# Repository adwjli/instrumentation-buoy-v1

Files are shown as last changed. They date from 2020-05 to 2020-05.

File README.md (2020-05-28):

# Instrumentation Buoy Data Logger

## Introduction

The client which I worked with in this project was working on a new concept to grow seaweed at an industrial scale (approximately 100km by 100km) in deep ocean waters tens of kilometres offshore. The seaweed plantation is kept afloat using buoys. One of the biggest challenge the client wanted to solve was how to keep the water near the surface of the ocean oxygenated to allow seaweed to grow. One idea was to use the motion of ocean waves to generate compressed air, which can be harnessed to pump air into the water to keep it oxygenated.



To aid in understanding how compressed air can be generated from ocean waves, a Instrumentation Buoy Data Logger was designed to measure various ocean metrics and record the data to a microSD card. The data logger had the following capabilities:
- Can measure water level and depth relative to the buoy.
- Can measure accelerations in all three spatial dimensions.
- Allows two pressure sensors to be connected to the board (via connectors located on the PCB)
- Designed to be completely solar powered. It is powered by an array of solar panels and a rechargeable 18650 Li-ion battery.
- A microSD card is used for data storage, but data transfer is done completely wirelessly using a XBee wireless module. The XBee module also allows over the air firmware updates. The solar-power and wireless capabilities of the data logger are necessary as the electronics will be permanently sealed away inside the buoy to ensure the electronics compartment is water-tight.

The data logger consists of two PCB assemblies sandwiched together. The smaller board is the Main Board. It contains the microcontroller, wireless module, and other digital electronics. The larger board is the Power Board which contains all the power electronics for solar charging. The entire PCB assembly is designed to be mounted in a prototype buoy, and deployed in the ocean to collect data.

The client has agreed to open source the designs.

## Gallery

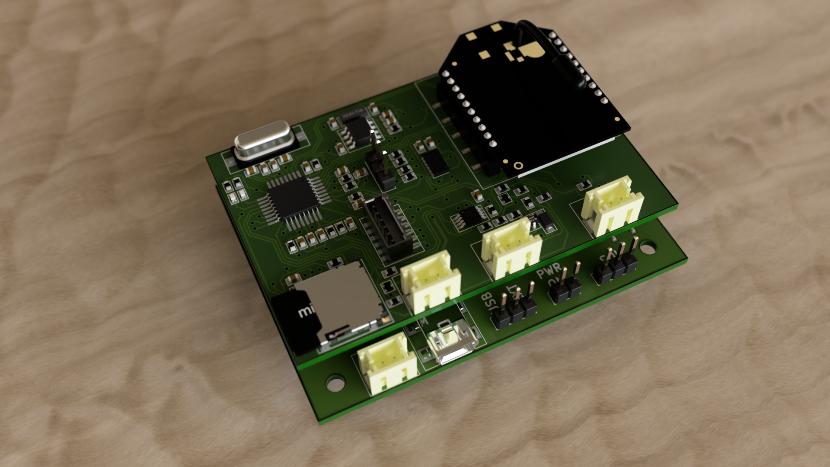
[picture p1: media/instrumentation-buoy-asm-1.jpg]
Instrumentation Buoy combined assembled - PCBA, image 1.


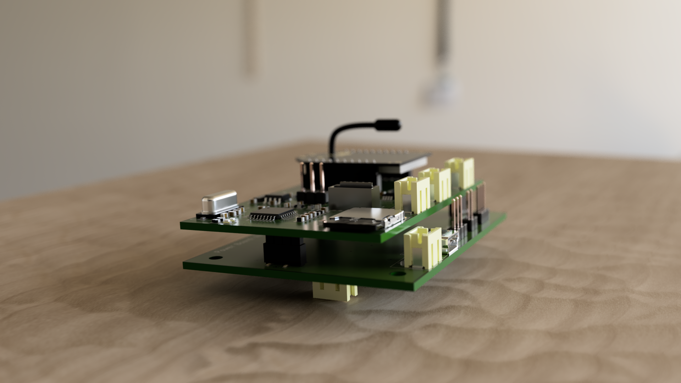
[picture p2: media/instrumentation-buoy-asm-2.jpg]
Instrumentation Buoy combined assembled - PCBA, image 2.


## PCB Assemblies
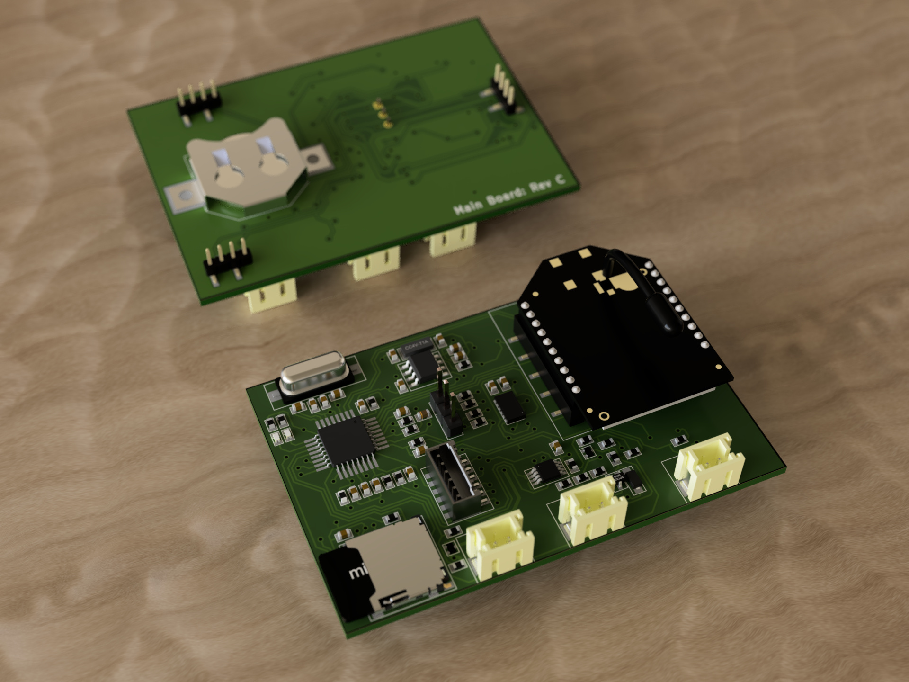
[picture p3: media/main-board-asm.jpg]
Instrumentation Buoy Main Board PCBA front and back.


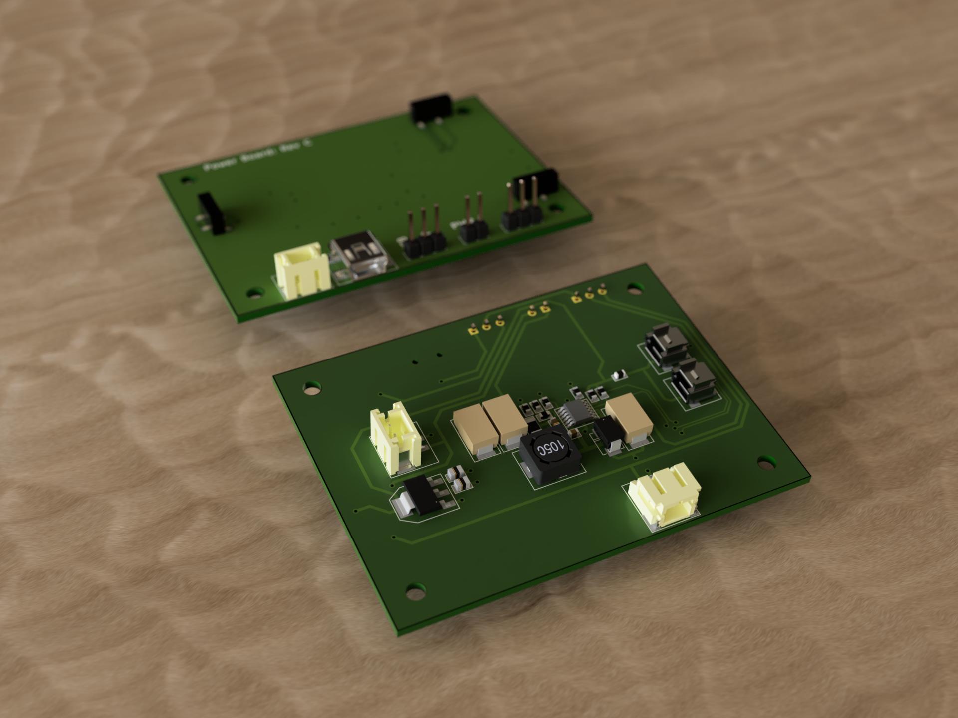
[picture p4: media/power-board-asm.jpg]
Instrumentation Buoy Power Board PCBA front and back.


## PCB Flats

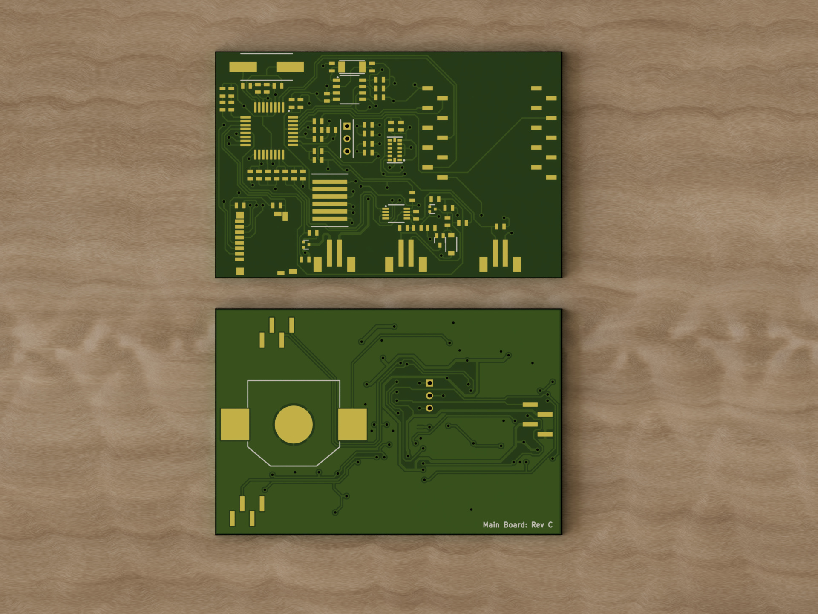
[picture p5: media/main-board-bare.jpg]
Instrumentation Buoy Main Board bare PCB.


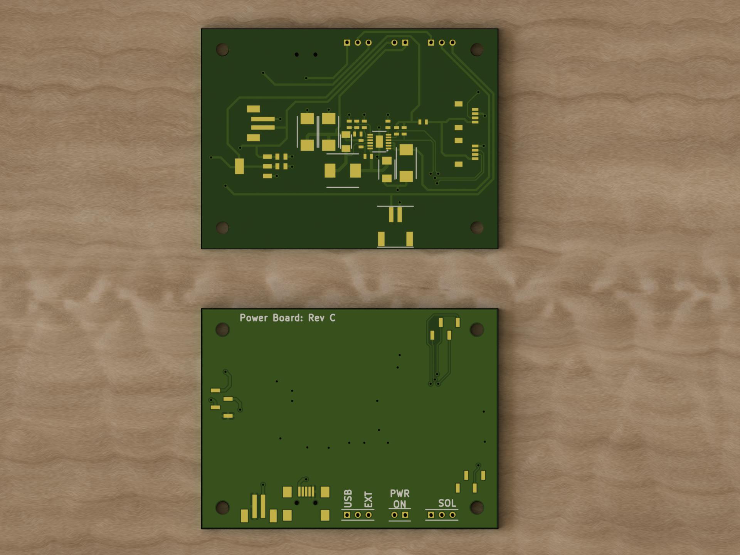
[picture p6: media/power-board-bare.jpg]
Instrumentation Buoy Power Board bare PCB.


## Copper Layers

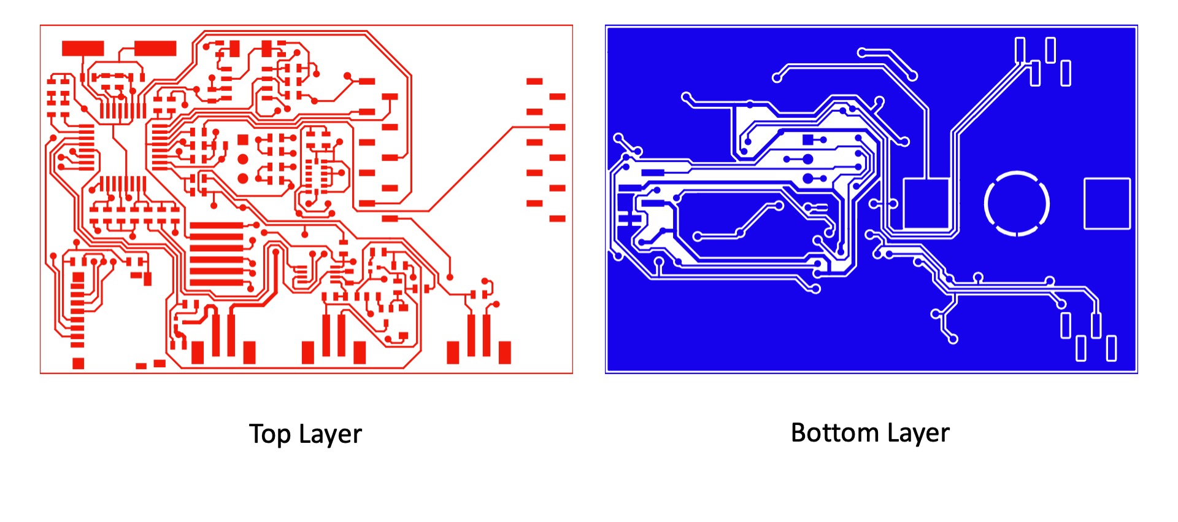
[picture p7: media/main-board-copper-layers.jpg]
Main Board - copper layers, top and bottom.


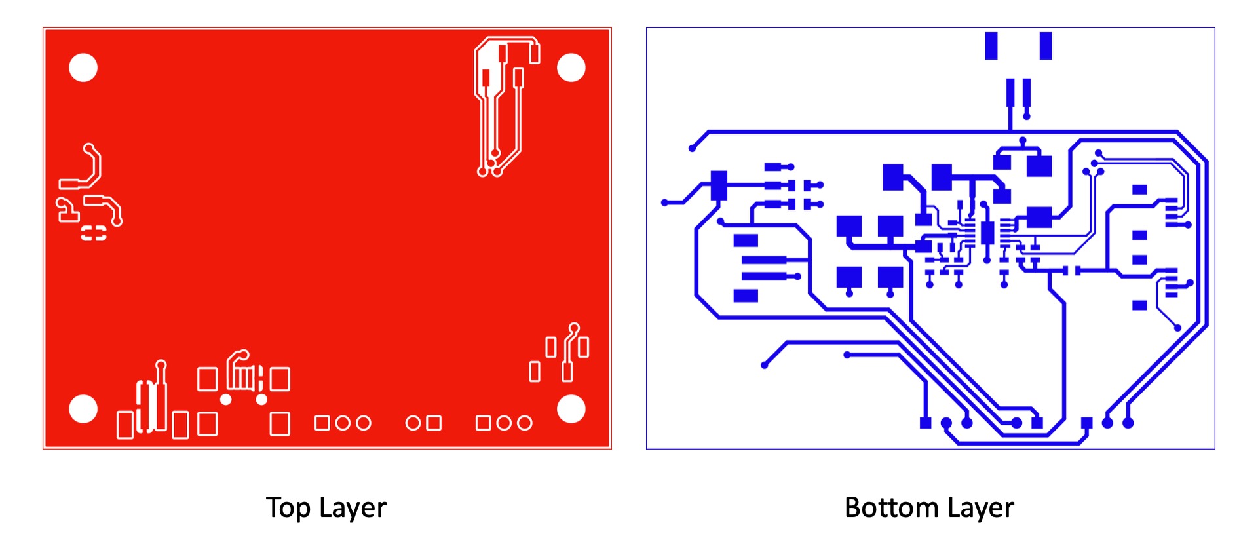
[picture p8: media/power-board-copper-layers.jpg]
Power Board - copper layers, top and bottom.


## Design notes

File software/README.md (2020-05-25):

# Firmware for Instrumentation Buoy

Compiled using the Arduino IDE. Copy the contents of the libraries folder into your Arduino `libraries` directory. To compile code, open the file `ob_datalogger.ino` and click *Verify* in the Arduino IDE.

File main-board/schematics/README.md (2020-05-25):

# Schematics

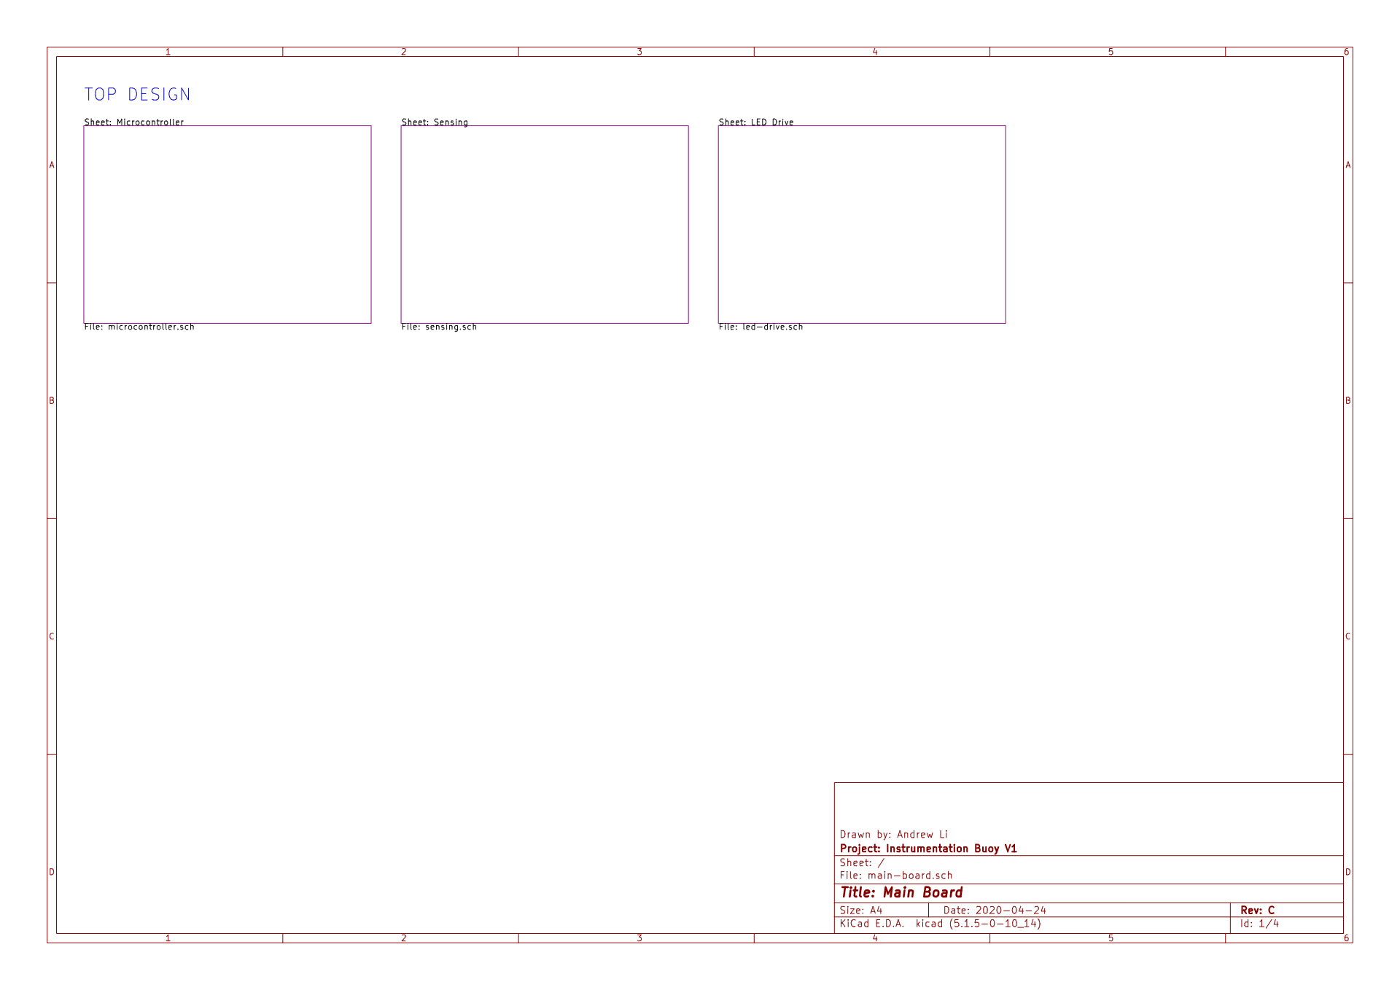
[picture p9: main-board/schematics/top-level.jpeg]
Schematics of Main Board - Top Level.


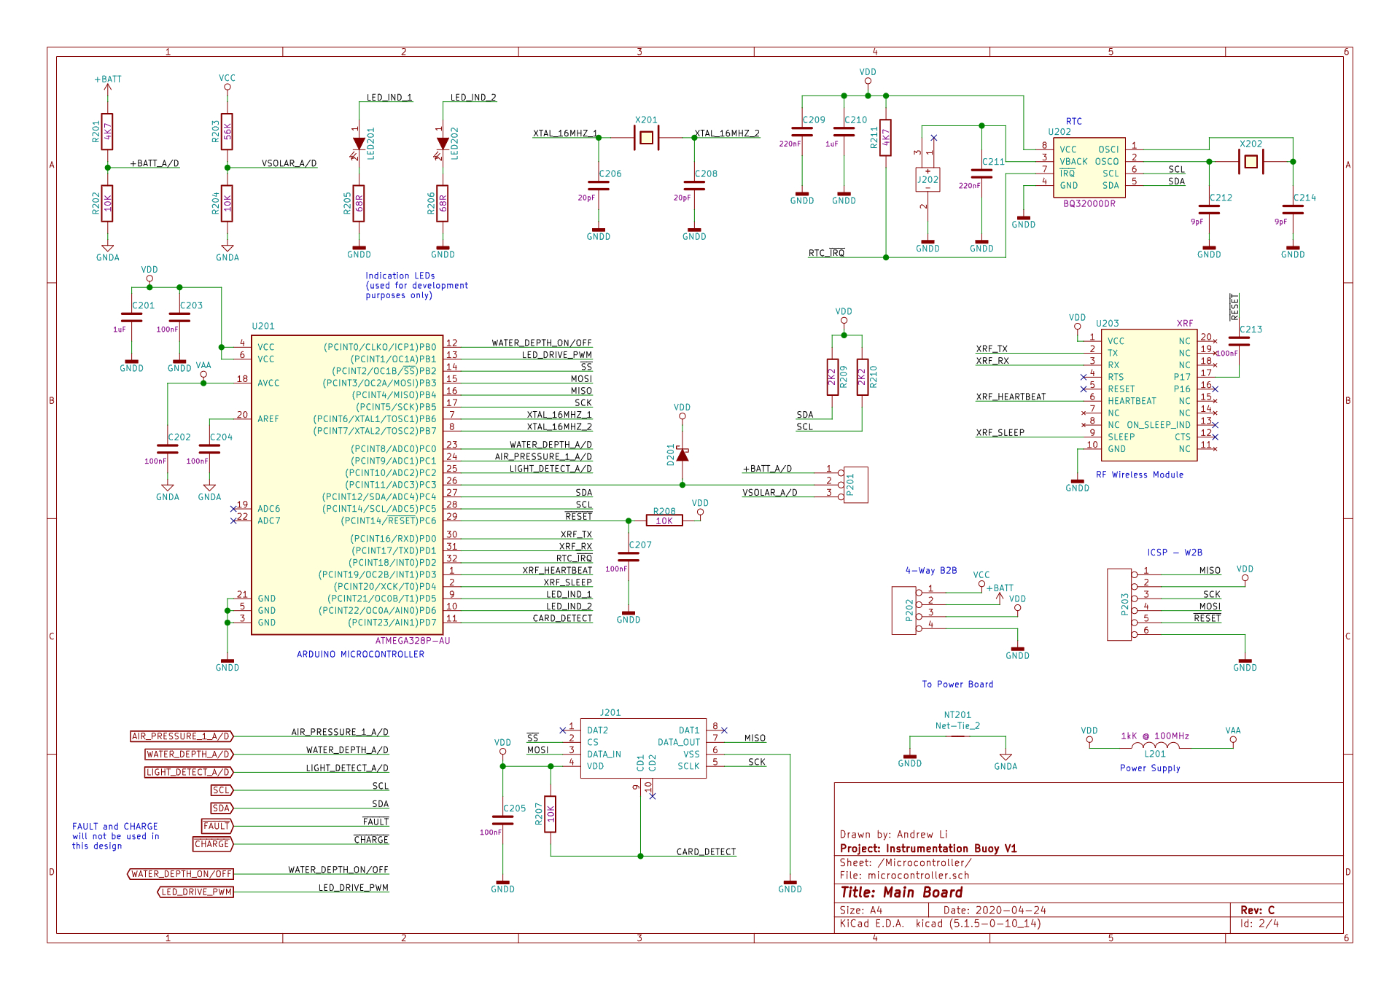
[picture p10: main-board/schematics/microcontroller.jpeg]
Schematics of Main Board - Microcontroller.


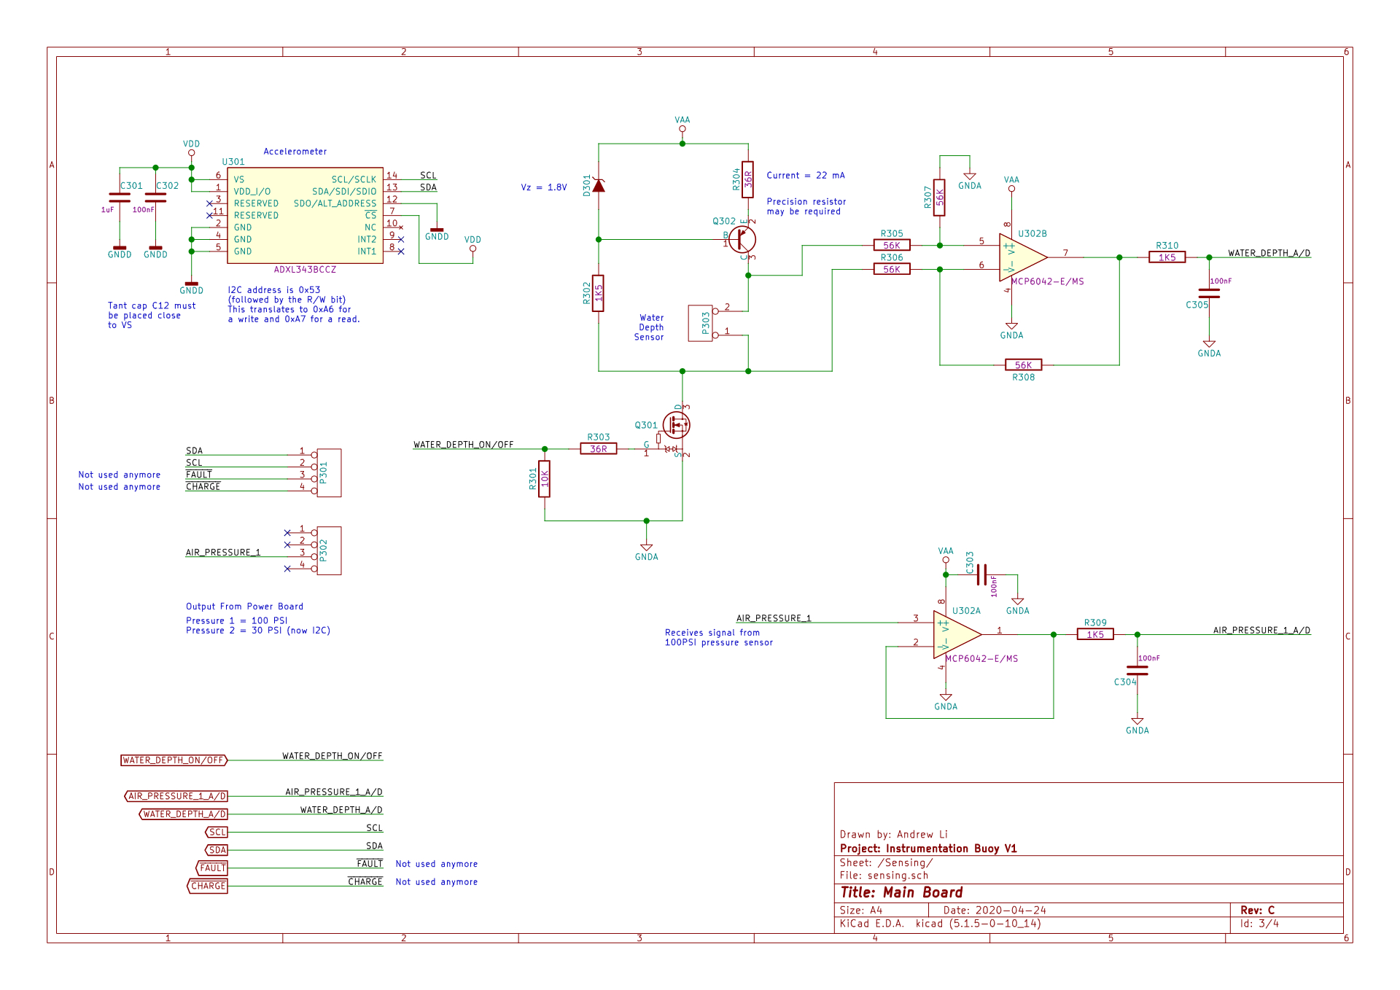
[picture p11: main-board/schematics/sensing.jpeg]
Schematics of Main Board - Sensing.


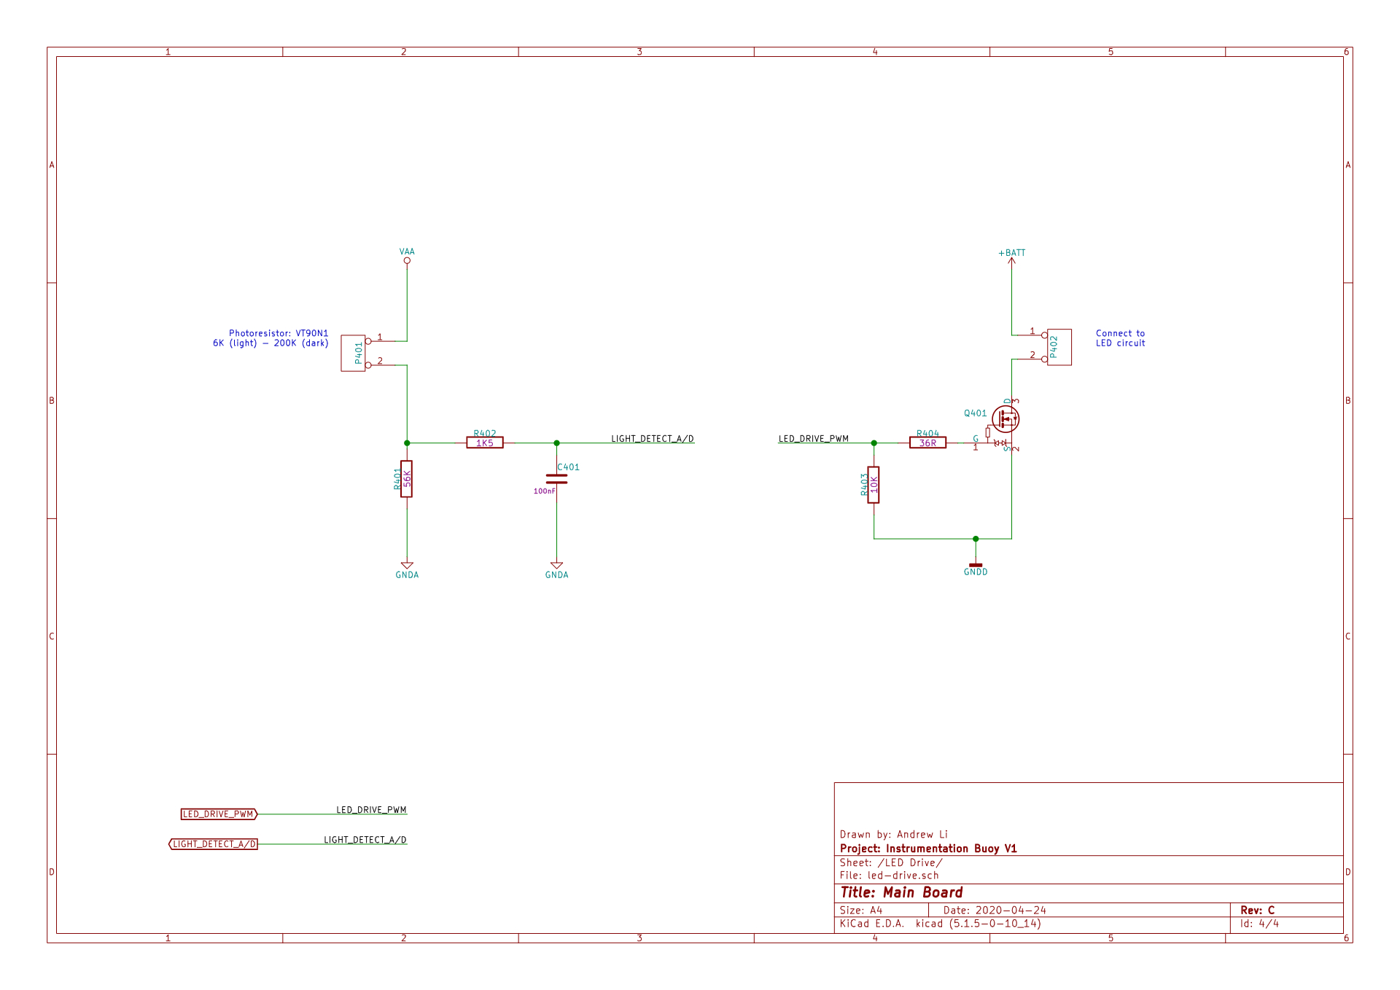
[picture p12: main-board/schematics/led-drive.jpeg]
Schematics of Main Board - LED Drive.


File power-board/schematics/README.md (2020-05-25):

# Schematics

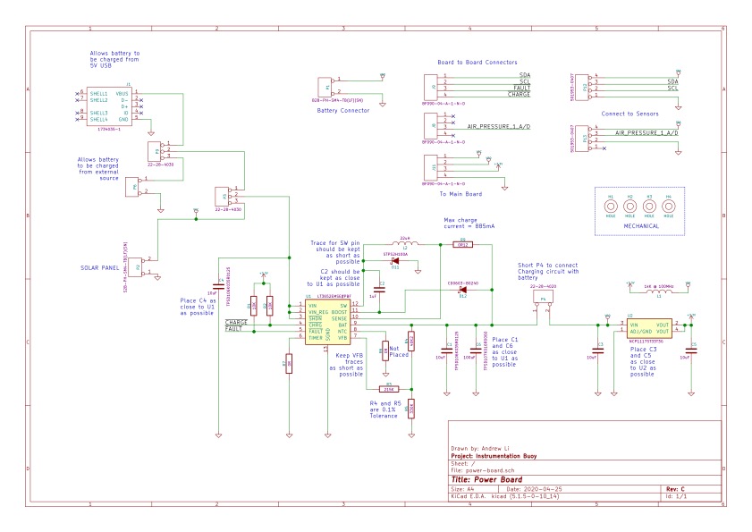
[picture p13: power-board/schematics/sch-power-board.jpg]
Schematics of Power Board.


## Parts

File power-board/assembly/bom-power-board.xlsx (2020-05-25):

Reference | Quantity | Internal Part Number | Component Value | Manufacturer | MPN | Part Description
C1 C4 | 2 | ECS00053 | 10uF | AVX | TPSD106K035R0125 | 10uF, 2917, 10%, 35V, Tantalum
C2 | 1 | ECS00052 | 1uF | Murata | GRM188R61H105KAALD | 1uF, 0603, 10%, 50V, X5R, Ceramic
C3 C5 | 2 | ECS00050 | 10uF | Murata | GRM21BR61A106KE19L | 10uF, 0805, 10%, 10V, X5R, Ceramic
C6 | 1 | ECS00054 | 100uF | AVX | TPSD107K016R0060 | 100uF, 2917, 10%, 16V, Tantalum
D11 | 1 | ECS00095 | ~ | ST Microelectronics | STPS2H100A | Schottky, Single, 2A, SMD
D12 | 1 | ECS00037 | ~ | Bourns | CD0603-B0240 | Schottky, Single, 0.1A, SMD
J1 | 1 | ECS00066 | ~ | TE Connectivity | 1734035-1 | Mini USB Type B, receptacle
J8 J9 J11 | 3 | ECS00059 | 4x1 | Global Connector Technology | BF090-04-A-1-N-D | 4-way, receptacle b-b, 2mm pitch, vertical, SMD, BF040 Series
L1 | 1 | ECS00074 | 1kK @ 100MHz | Murata | BLM18TG102TN1D | 1K @ 100MHz, 0603, 0.1A, 0R6
L2 | 1 | ECS00071 | 22uH | Murata | 46223C | 22uH, 1.8A, 0R12
P1 P6 | 2 | ECS00067 | 2x1 | JST | B2B-PH-SM4-TB(LF)(SN) | 2-way, header, 2mm pitch, vertical, SMD, PH Series
P12 P13 | 2 | ECS00068 | 4x1 | Molex | 501953-0407 | 4-way, header, 1mm pitch, right angle, SMD, Pico-Clasp 501953 Series
P2 | 1 | ECS00007 | 2x1 | JST | S2B-PH-SM4-TB(LF)(SN) | 2-way, header, 2mm pitch, right angle, SMD, PH Series
P4 | 1 | ECS00004 | 2x1 | Molex | 22-28-4020 | 2-way, header, 2.54mm pitch, vertical, through hole, KK Series
P9 P3 | 2 | ECS00013 | 3x1 | Molex | 22-28-4030 | 3-way, header, 2.54mm pitch, vertical, through hole, KK Series
R2 R1 | 2 | ECS00045 | 10K | Panasonic | ERJ3GEYJ103V | 10K, 0603, 5%, 0.1W, Thick Film
R3 | 1 | ECS00046 | 215K | Panasonic | ERJ3EKF2153V | 215K, 0603, 1%, 0.1W, Thick Film
R4 | 1 | ECS00048 | 40K2 | Panasonic | ERA3ARB4022V | 40K2, 0603, 0.1%, 0.1W, Thin Film
R5 | 1 | ECS00047 | 330K | Panasonic | ERJ3EKF3303V | 330K, 0603, 1%, 0.1W, Thick Film
R7 R6 | 2 | ECS00058 | 0R | Panasonic | ERJ3GEY0R00V | 0R, 0603, 0.1W, Jumper
R9 | 1 | ECS00055 | 0R12 | Bourns | CRL1206-FW-R120ELF | 0R12, 1206, 1%, 0.25W, Thick Film
U1 | 1 | ECS00043 | ~ | Linear Technology | LT3652EMSE#PBF | Switch Mode Charge Controller with MPPT
U2 | 1 | ECS00036 | ~ | On Semiconductor | NCP1117ST33T3G | 3.3V Linear Regulator

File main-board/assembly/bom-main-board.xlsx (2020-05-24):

Reference | Quantity | Internal Part Number | Component Value | Manufacturer | Manufacturer Part Number | Part Description
C201 C210 C301 | 3 | ECS00052 | 1uF | Murata | GRM188R61H105KAALD | 1uF, 0603, 10%, 50V, X5R, Ceramic
C203 C202 C204 C207 C205 C213 C302 C305 C304 C303 C401 | 11 | ECS00075 | 100nF | Murata | GRM188R71C104KA01D | 100nF, 0603, 10%, 16V, X7R, Ceramic
C206 C208 | 2 | ECS00077 | 20pF | Kemet | C0603C200J5GACTU | 20pF, 0603, 5%, 50V, NP0, Ceramic
C209 C211 | 2 | ECS00078 | 220nF | Murata | GRM188R71A224KA01D | 220nF, 0603, 10%, 10V, X7R, Ceramic
C212 C214 | 2 | ECS00076 | 9pF | Multicomp | MC0603N9R0D500CT | 9pF, 0603, ¬±5pF, 50V, NP0, Ceramic
D201 | 1 | ECS00037 | ~ | Bourns | CD0603-B0240 | Schottky, Single, 0.1A, SMD
D301 | 1 | ECS00072 | 1.8V | On Semiconductor | MMSZ4678T1G | Zener, 1.8V, 0.25W, SMD
J201 | 1 | ECS00065 | ~ | Amphenol Commercial Products | 114-00841-68 | Micro SD Card Holder, SMD
J202 | 1 | ECS00094 | 16mm | Memory Protection Devices | BK-868 | Retainer, 16mm Diameter Cell, SMD
L201 | 1 | ECS00074 | 1kK @ 100MHz | Murata | BLM18TG102TN1D | 1K @ 100MHz, 0603, 0.1A, 0R6
LED201 LED202 | 2 | ECS00035 | Red | Rohm | SML-310VTT86L | Red, 4mcd, 0603
P201 | 1 | ECS00013 | 3x1 | Molex | 22-28-4030 | 3-way, header, 2.54mm pitch, vertical, through hole, KK Series
P202 P302 P301 | 3 | ECS00029 | 4x1 | Global Connector Technology | BF040-04A-B2-0400-0260-0483-LD | 4-way, header, 2mm pitch, 4mm height, vertical, SMD, BF040 Series
P203 | 1 | ECS00015 | 6x1 | Molex | 87437-0673 | 6-way, header, 1.5mm pitch, vertical, SMD, Pico-SPOX Series
P303 P401 P402 | 3 | ECS00067 | 2x1 | JST | B2B-PH-SM4-TB(LF)(SN) | 2-way, header, 2mm pitch, vertical, SMD, PH Series
Q301 Q401 | 2 | ECS00087 | ~ | On Semiconductor | NTA4153NT1G | MOSFET, N-Channel, 0.915A, 0R127
Q302 | 1 | ECS00073 | ~ | NXP | BC857BW,115 | BJT, PNP, 45V, 0.1A
R201 R211 | 2 | ECS00086 | 4K7 | Bourns | CR0603-FX-4701ELF | 4K7, 0603, 1%, 0.063W, Thick Film
R202 R207 R208 R204 R301 R403 | 6 | ECS00045 | 10K | Panasonic | ERJ3GEYJ103V | 10K, 0603, 5%, 0.1W, Thick Film
R203 R307 R308 R306 R305 R401 | 6 | ECS00085 | 56K | Vishay | CRCW060356K0FKEAHP | 56K, 0603, 1%, 0.25W, Thick Film, High Power
R205 R206 | 2 | ECS00081 | 68R | Bourns | CR0603-FX-68R0ELF | 68R, 0603, 1%, 0.1W, Thick Film
R210 R209 | 2 | ECS00084 | 2K2 | Multicomp | MC0063W060312K2 | 2K2, 0603, 1%, 0.063W, Thick Film
R302 R309 R310 R402 | 4 | ECS00083 | 1K5 | Bourns | CR0603-FX-1501ELF | 1K5, 0603, 1%, 0.1W, Thick Film
R303 R304 R404 | 3 | ECS00080 | 36R | Vishay | CRCW060336R0FKEA | 36R, 0603, 0.1W, Thick Film
U201 | 1 | ECS00017 | ~ | Atmel | ATMEGA328P-AU | ATMega328P, TQFP
U202 | 1 | ECS00032 | ~ | Texas Instruments | BQ32000DR | RTC, 8SOIC
U203 | 1 | ECA00002 | ~ | Ciseco PLC | XRF | XRF Wireless UART Serial Data Module
U301 | 1 | ECS00016 | ~ | Analog Device | ADXL343BCCZ | Accelerometer, 3 axis
U302 | 1 | ECS00030 | ~ | Microchip | MCP6042-E/MS | Dual Package, 8-MSOP, Unity Gain Stable
X201 | 1 | ECS00006 | 16MHz | Fox | FOXSDLF/160-20 | Crystal, 16MHz, 30ppm, 20pF, SMD
X202 | 1 | ECS00005 | 32.768kHz | Micro Crystal Switzerland | CC4V-T1A 32.768KHZ +-20PPM 9PF | Crystal, 32.768kHz, 20ppm, 9pF, SMD

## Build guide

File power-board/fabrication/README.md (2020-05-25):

# Fabrication Drawing

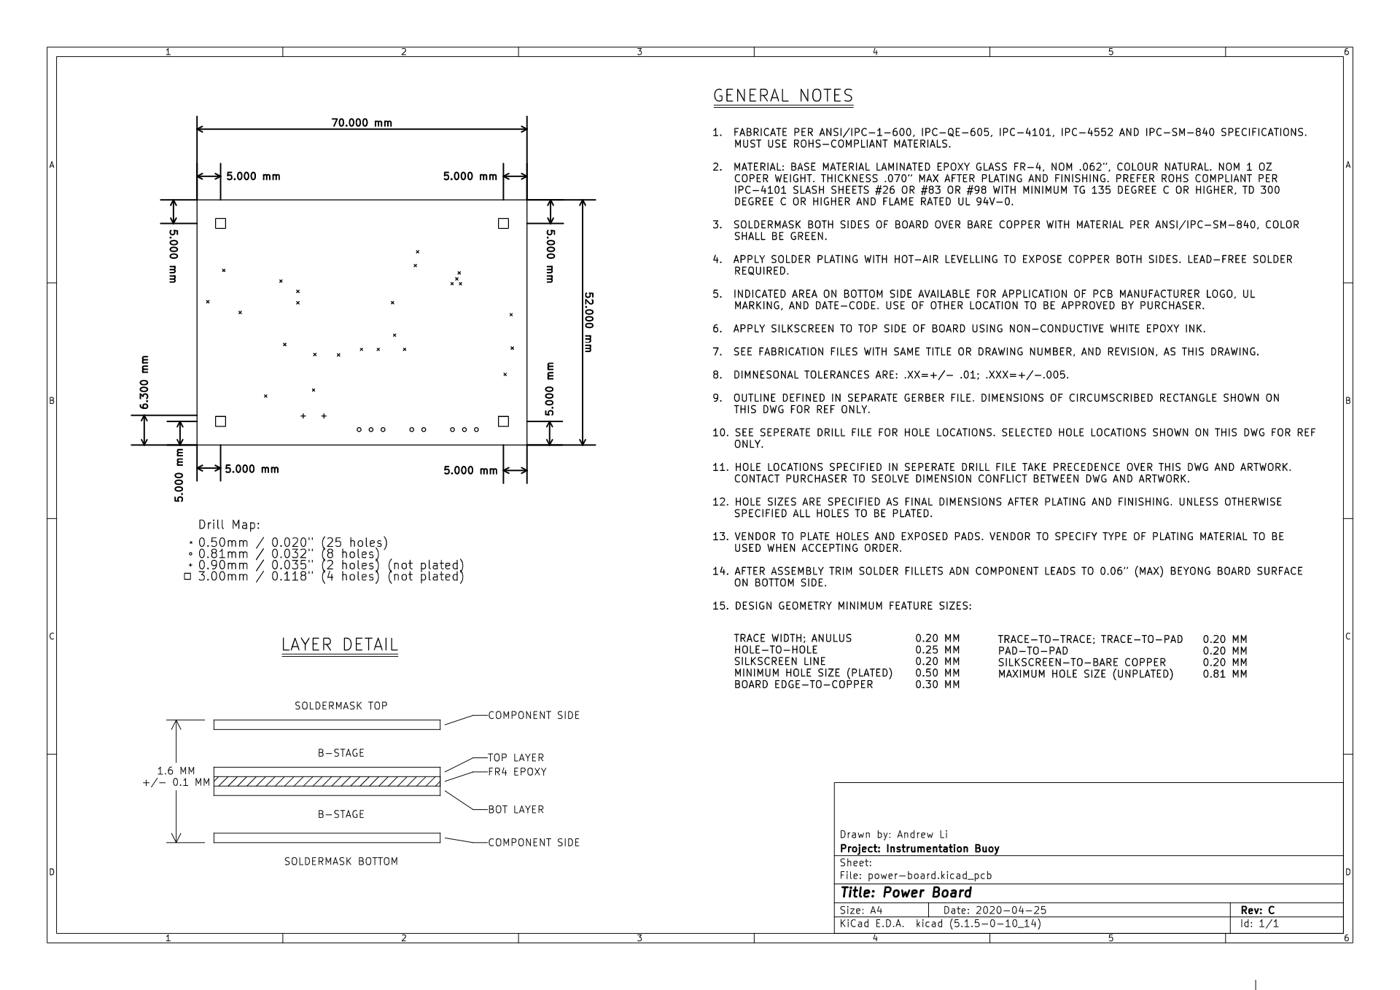
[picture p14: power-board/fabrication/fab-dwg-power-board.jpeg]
Fabrication drawing


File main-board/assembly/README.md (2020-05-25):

# Assembly Drawing

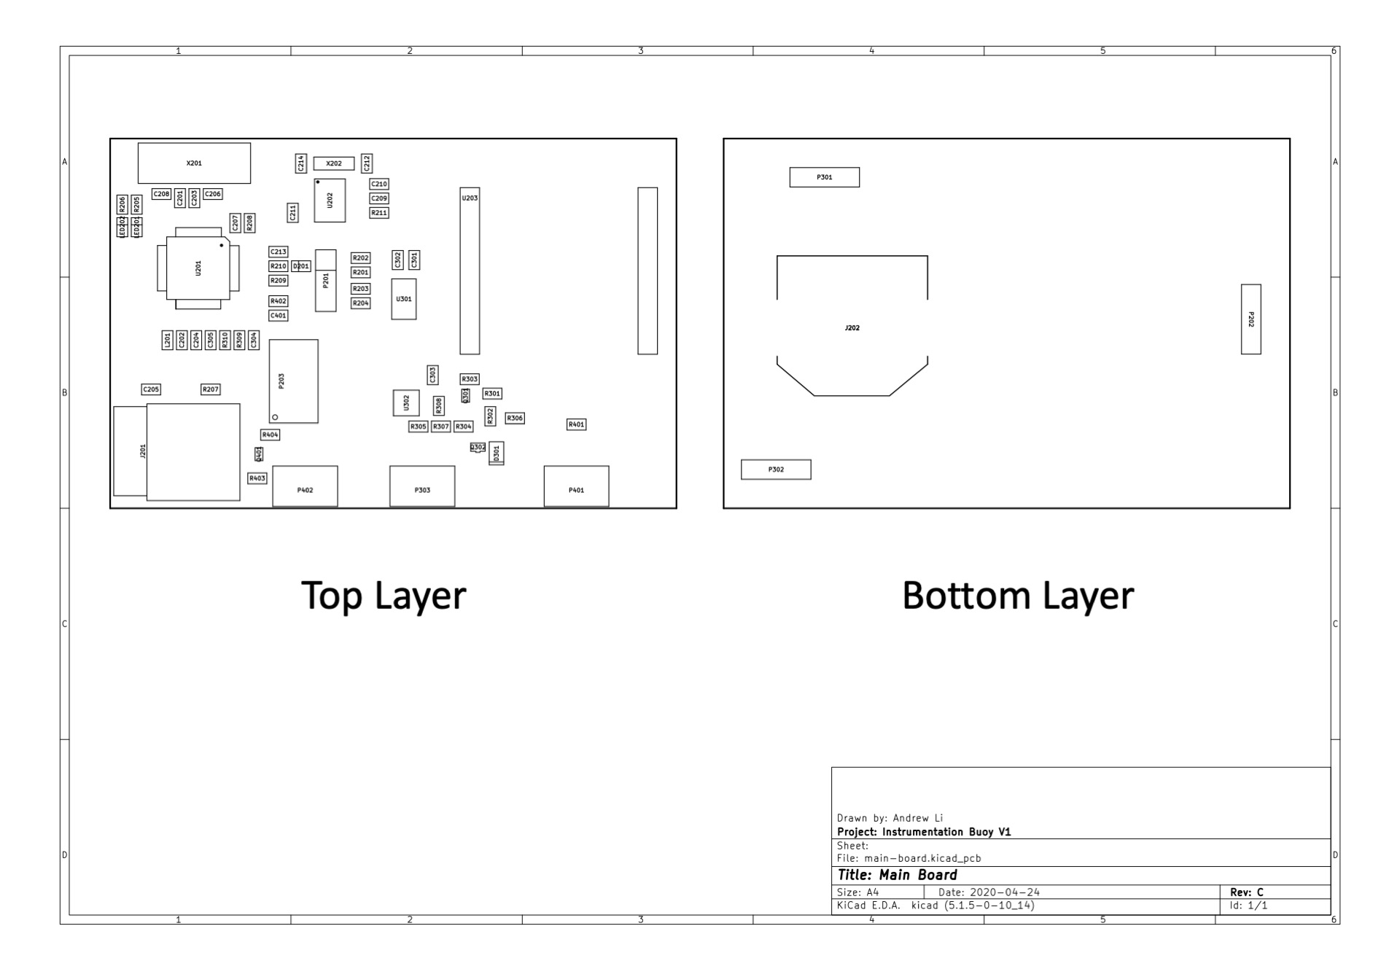
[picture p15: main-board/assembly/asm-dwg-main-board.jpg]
Assembly Drawing.


## Bill of Materials

| Reference 	|  Quantity 	| Internal Part Number 	|  Component Value 	|  Manufacturer 	|  MPN 	|  Part Description 	|
|---	|---	|---	|---	|---	|---	|---	|
| C201 C210 C301 	| 3 	| ECS00052 	| 1uF 	| Murata 	| GRM188R61H105KAALD 	| 1uF, 0603, 10%, 50V, X5R, Ceramic 	|
| C203 C202 C204 C207 C205 C213 C302 C305 C304 C303 C401  	| 11 	| ECS00075 	| 100nF 	| Murata 	| GRM188R71C104KA01D 	| 100nF, 0603, 10%, 16V, X7R, Ceramic 	|
| C206 C208 	| 2 	| ECS00077 	| 20pF 	| Kemet 	| C0603C200J5GACTU 	| 20pF, 0603, 5%, 50V, NP0, Ceramic 	|
| C209 C211 	| 2 	| ECS00078 	| 220nF 	| Murata 	| GRM188R71A224KA01D 	| 220nF, 0603, 10%, 10V, X7R, Ceramic 	|
| C212 C214 	| 2 	| ECS00076 	| 9pF 	| Multicomp 	| MC0603N9R0D500CT 	| 9pF, 0603, ¬±5pF, 50V, NP0, Ceramic 	|
| D201 	| 1 	| ECS00037 	| ~ 	| Bourns 	| CD0603-B0240 	| Schottky, Single, 0.1A, SMD 	|
| D301 	| 1 	| ECS00072 	| 1.8V 	| On Semiconductor 	| MMSZ4678T1G 	| Zener, 1.8V, 0.25W, SMD 	|
| J201 	| 1 	| ECS00065 	| ~ 	| Amphenol Commercial Products 	| 114-00841-68 	| Micro SD Card Holder, SMD 	|
| J202 	| 1 	| ECS00094 	| 16mm 	| Memory Protection Devices 	| BK-868 	| Retainer, 16mm Diameter Cell, SMD 	|
| L201 	| 1 	| ECS00074 	| 1kK @ 100MHz 	| Murata 	| BLM18TG102TN1D 	| 1K @ 100MHz, 0603, 0.1A, 0R6 	|
| LED201 LED202 	| 2 	| ECS00035 	| Red 	| Rohm 	| SML-310VTT86L 	| Red, 4mcd, 0603 	|
| P201 	| 1 	| ECS00013 	| 3x1 	| Molex 	| 22-28-4030 	| 3-way, header, 2.54mm pitch, vertical, through hole, KK Series 	|
| P202 P302 P301 	| 3 	| ECS00029 	| 4x1 	| Global Connector Technology  	| BF040-04A-B2-0400-0260-0483-LD 	| 4-way, header, 2mm pitch, 4mm height, vertical, SMD, BF040 Series 	|
| P203 	| 1 	| ECS00015 	| 6x1 	| Molex 	| 87437-0673 	| 6-way, header, 1.5mm pitch, vertical, SMD, Pico-SPOX Series 	|
| P303 P401 P402 	| 3 	| ECS00067 	| 2x1 	| JST 	| B2B-PH-SM4-TB(LF)(SN) 	| 2-way, header, 2mm pitch, vertical, SMD, PH Series 	|
| Q301 Q401 	| 2 	| ECS00087 	| ~ 	| On Semiconductor 	| NTA4153NT1G 	| MOSFET, N-Channel, 0.915A, 0R127 	|
| Q302 	| 1 	| ECS00073 	| ~ 	| NXP 	| BC857BW,115 	| BJT, PNP, 45V, 0.1A 	|
| R201 R211 	| 2 	| ECS00086 	| 4K7 	| Bourns 	| CR0603-FX-4701ELF 	| 4K7, 0603, 1%, 0.063W, Thick Film 	|
| R202 R207 R208 R204 R301 R403 	| 6 	| ECS00045 	| 10K 	| Panasonic 	| ERJ3GEYJ103V 	| 10K, 0603, 5%, 0.1W, Thick Film 	|
| R203 R307 R308 R306 R305 R401 	| 6 	| ECS00085 	| 56K 	| Vishay 	| CRCW060356K0FKEAHP 	| 56K, 0603, 1%, 0.25W, Thick Film, High Power 	|
| R205 R206 	| 2 	| ECS00081 	| 68R 	| Bourns 	| CR0603-FX-68R0ELF 	| 68R, 0603, 1%, 0.1W,  Thick Film 	|
| R210 R209 	| 2 	| ECS00084 	| 2K2 	| Multicomp 	| MC0063W060312K2 	| 2K2, 0603, 1%, 0.063W, Thick Film 	|
| R302 R309 R310 R402 	| 4 	| ECS00083 	| 1K5 	| Bourns 	| CR0603-FX-1501ELF 	| 1K5, 0603, 1%,  0.1W, Thick Film 	|
| R303 R304 R404 	| 3 	| ECS00080 	| 36R 	| Vishay 	| CRCW060336R0FKEA 	| 36R, 0603, 0.1W,  Thick Film 	|
| U201 	| 1 	| ECS00017 	| ~ 	| Atmel 	| ATMEGA328P-AU 	| ATMega328P, TQFP 	|
| U202 	| 1 	| ECS00032 	| ~ 	| Texas Instruments 	| BQ32000DR 	| RTC, 8SOIC 	|
| U203 	| 1 	| ECA00002 	| ~ 	| Ciseco PLC 	| XRF 	| XRF Wireless UART Serial Data Module 	|
| U301 	| 1 	| ECS00016 	| ~ 	| Analog Device 	| ADXL343BCCZ 	| Accelerometer, 3 axis 	|
| U302 	| 1 	| ECS00030 	| ~ 	| Microchip 	| MCP6042-E/MS 	| Dual Package, 8-MSOP, Unity Gain Stable 	|
| X201 	| 1 	| ECS00006 	| 16MHz 	| Fox 	| FOXSDLF/160-20 	| Crystal, 16MHz, 30ppm, 20pF, SMD 	|
| X202 	| 1 	| ECS00005 	| 32.768kHz 	| Micro Crystal Switzerland 	| CC4V-T1A 32.768KHZ +-20PPM 9PF 	| Crystal, 32.768kHz, 20ppm, 9pF, SMD 	|

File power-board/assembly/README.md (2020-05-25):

# Assembly Drawing

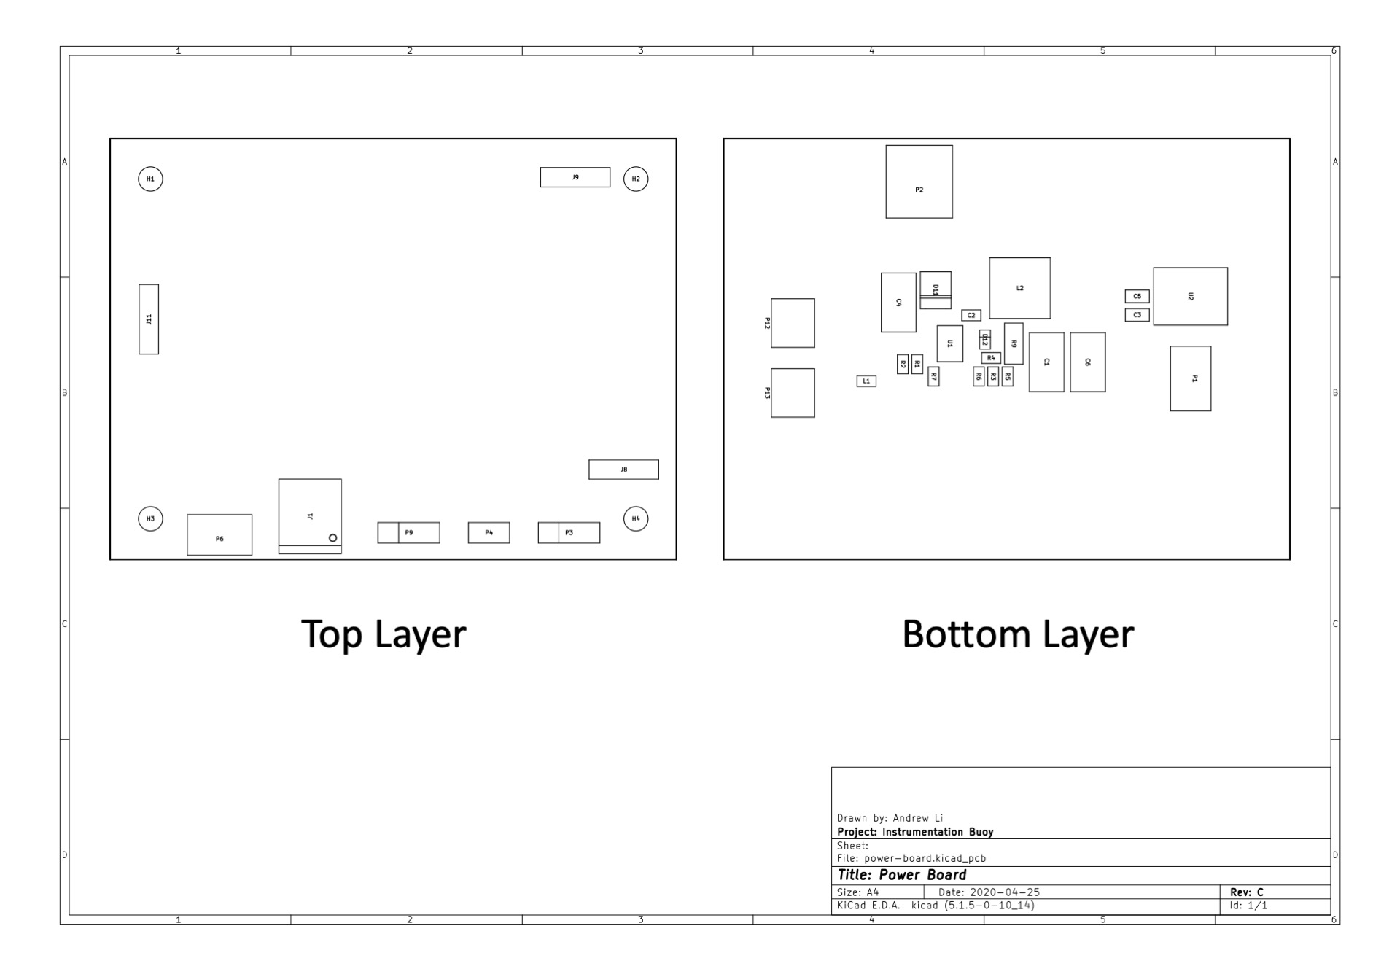
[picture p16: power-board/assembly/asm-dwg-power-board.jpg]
Assembly drawing


## Bill of Materials

| Reference  	|  Quantity 	|  Internal Part Number 	|  Component Value 	|  Manufacturer 	| MPN 	|  Part Description 	|
|---	|:---:	|---	|---	|---	|---	|---	|
| C1 C4 	| 2 	| ECS00053 	| 10uF 	| AVX 	| TPSD106K035R0125 	| 10uF, 2917, 10%, 35V, Tantalum 	|
| C2 	| 1 	| ECS00052 	| 1uF 	| Murata 	| GRM188R61H105KAALD 	| 1uF, 0603, 10%, 50V, X5R, Ceramic 	|
| C3 C5 	| 2 	| ECS00050 	| 10uF 	| Murata 	| GRM21BR61A106KE19L 	| 10uF, 0805, 10%, 10V, X5R, Ceramic 	|
| C6 	| 1 	| ECS00054 	| 100uF 	| AVX 	| TPSD107K016R0060 	| 100uF, 2917, 10%, 16V, Tantalum 	|
| D11 	| 1 	| ECS00095 	| ~ 	| ST Microelectronics 	| STPS2H100A 	| Schottky, Single, 2A, SMD 	|
| D12 	| 1 	| ECS00037 	| ~ 	| Bourns 	| CD0603-B0240 	| Schottky, Single, 0.1A, SMD 	|
| J1 	| 1 	| ECS00066 	| ~ 	| TE Connectivity 	| 1734035-1 	| Mini USB Type B, receptacle 	|
| J8 J9 J11  	| 3 	| ECS00059 	| 4x1 	| Global Connector Technology 	| BF090-04-A-1-N-D 	| 4-way, receptacle b-b, 2mm pitch, vertical, SMD, BF040 Series 	|
| L1 	| 1 	| ECS00074 	| 1kK @ 100MHz 	| Murata 	| BLM18TG102TN1D 	| 1K @ 100MHz, 0603, 0.1A, 0R6 	|
| L2 	| 1 	| ECS00071 	| 22uH 	| Murata 	| 46223C 	| 22uH, 1.8A, 0R12 	|
| P1 P6 	| 2 	| ECS00067 	| 2x1 	| JST 	| B2B-PH-SM4-TB(LF)(SN) 	| 2-way, header, 2mm pitch, vertical, SMD, PH Series 	|
| P12 P13 	| 2 	| ECS00068 	| 4x1 	| Molex 	| 501953-0407 	| 4-way, header, 1mm pitch, right angle, SMD, Pico-Clasp 501953 Series 	|
| P2 	| 1 	| ECS00007 	| 2x1 	| JST 	| S2B-PH-SM4-TB(LF)(SN) 	| 2-way, header, 2mm pitch, right angle, SMD, PH Series 	|
| P4 	| 1 	| ECS00004 	| 2x1 	| Molex 	| 22-28-4020 	| 2-way, header, 2.54mm pitch, vertical, through hole, KK Series 	|
| P9 P3 	| 2 	| ECS00013 	| 3x1 	| Molex 	| 22-28-4030 	| 3-way, header, 2.54mm pitch, vertical, through hole, KK Series 	|
| R2 R1 	| 2 	| ECS00045 	| 10K 	| Panasonic 	| ERJ3GEYJ103V 	| 10K, 0603, 5%, 0.1W, Thick Film 	|
| R3 	| 1 	| ECS00046 	| 215K 	| Panasonic 	| ERJ3EKF2153V 	| 215K, 0603, 1%, 0.1W, Thick Film 	|
| R4 	| 1 	| ECS00048 	| 40K2 	| Panasonic 	| ERA3ARB4022V 	| 40K2, 0603, 0.1%, 0.1W, Thin Film 	|
| R5 	| 1 	| ECS00047 	| 330K 	| Panasonic 	| ERJ3EKF3303V 	| 330K,  0603, 1%, 0.1W, Thick Film 	|
| R7 R6 	| 2 	| ECS00058 	| 0R 	| Panasonic 	| ERJ3GEY0R00V 	| 0R, 0603, 0.1W, Jumper 	|
| R9 	| 1 	| ECS00055 	| 0R12 	| Bourns 	| CRL1206-FW-R120ELF 	| 0R12, 1206, 1%, 0.25W, Thick Film 	|
| U1 	| 1 	| ECS00043 	| ~ 	| Linear Technology 	| LT3652EMSE#PBF 	| Switch Mode Charge Controller with MPPT 	|
| U2 	| 1 	| ECS00036 	| ~ 	| On Semiconductor 	| NCP1117ST33T3G 	| 3.3V Linear Regulator 	|

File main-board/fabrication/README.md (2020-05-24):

# Fabrication Drawing

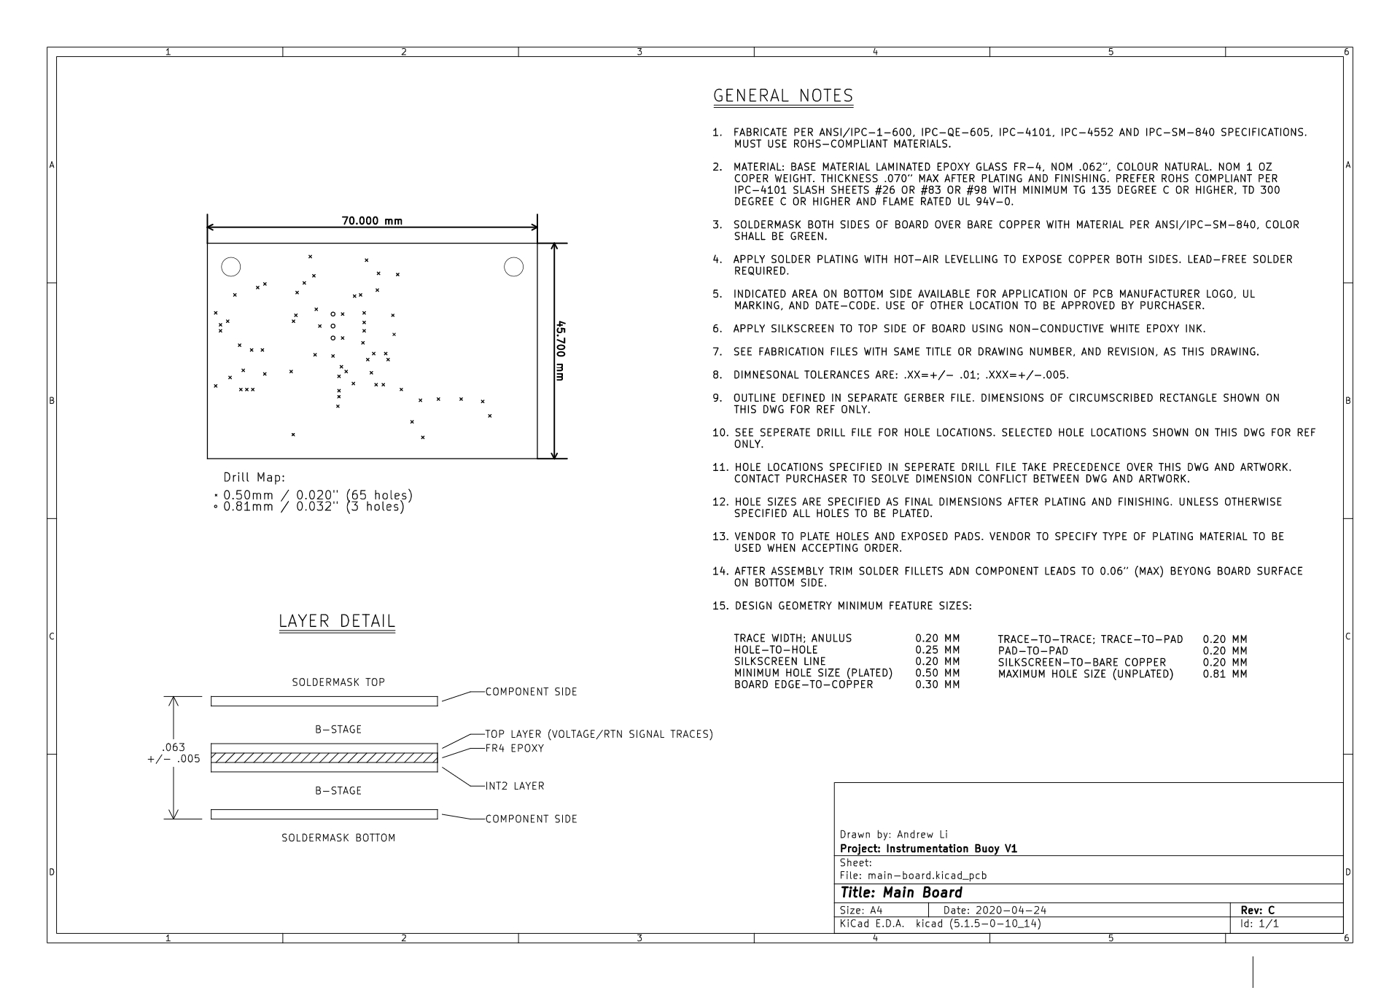
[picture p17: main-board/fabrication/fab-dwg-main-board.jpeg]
Fabrication Drawing.


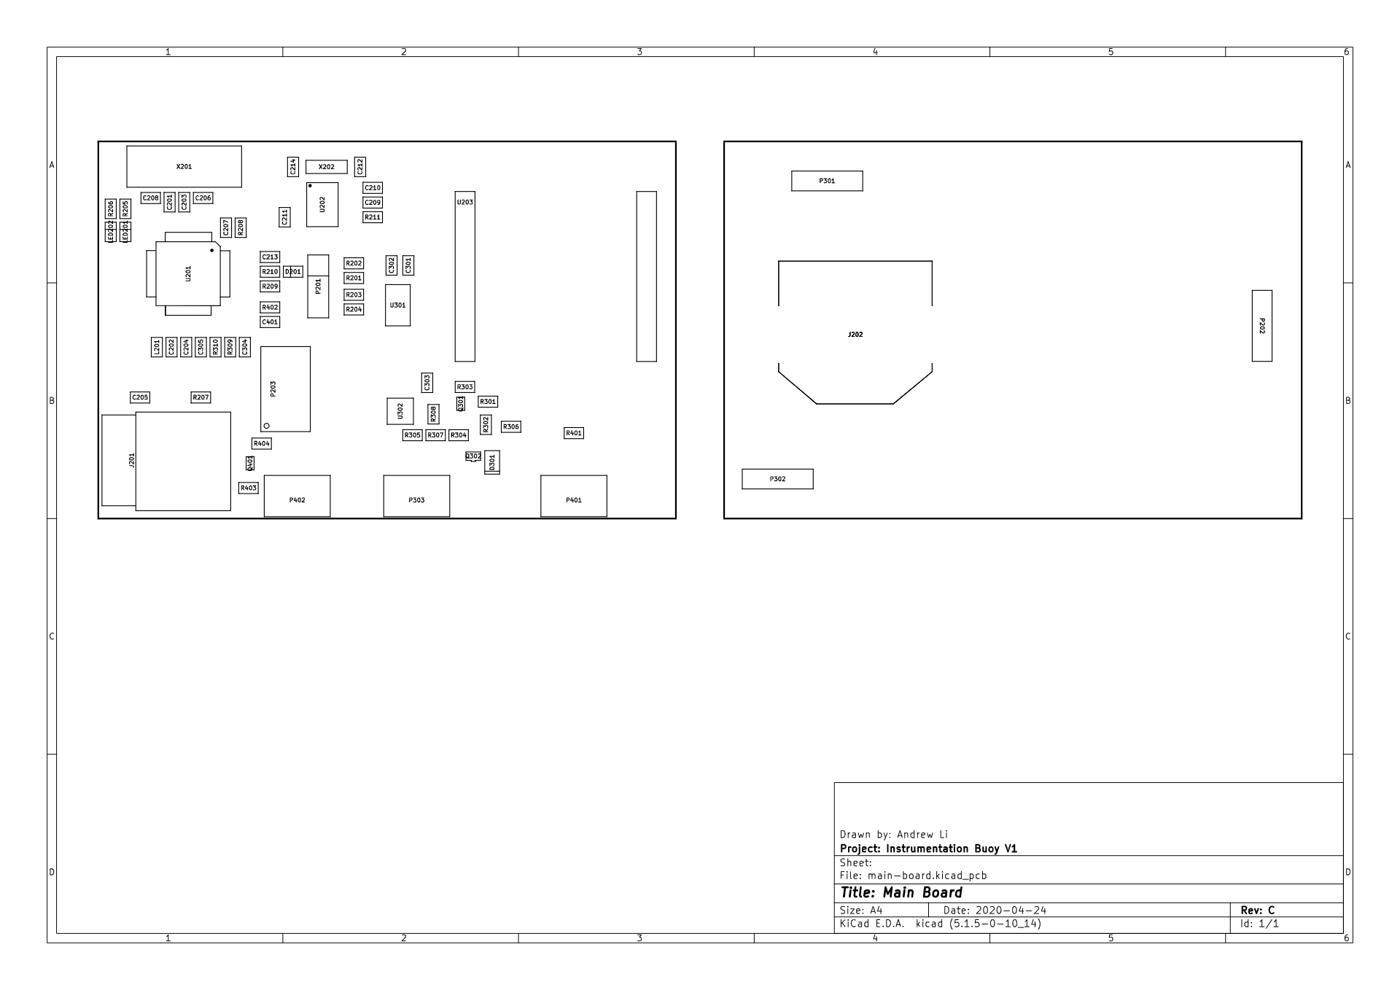
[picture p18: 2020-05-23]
main-board/assembly/asm-dwg-main-board.jpeg

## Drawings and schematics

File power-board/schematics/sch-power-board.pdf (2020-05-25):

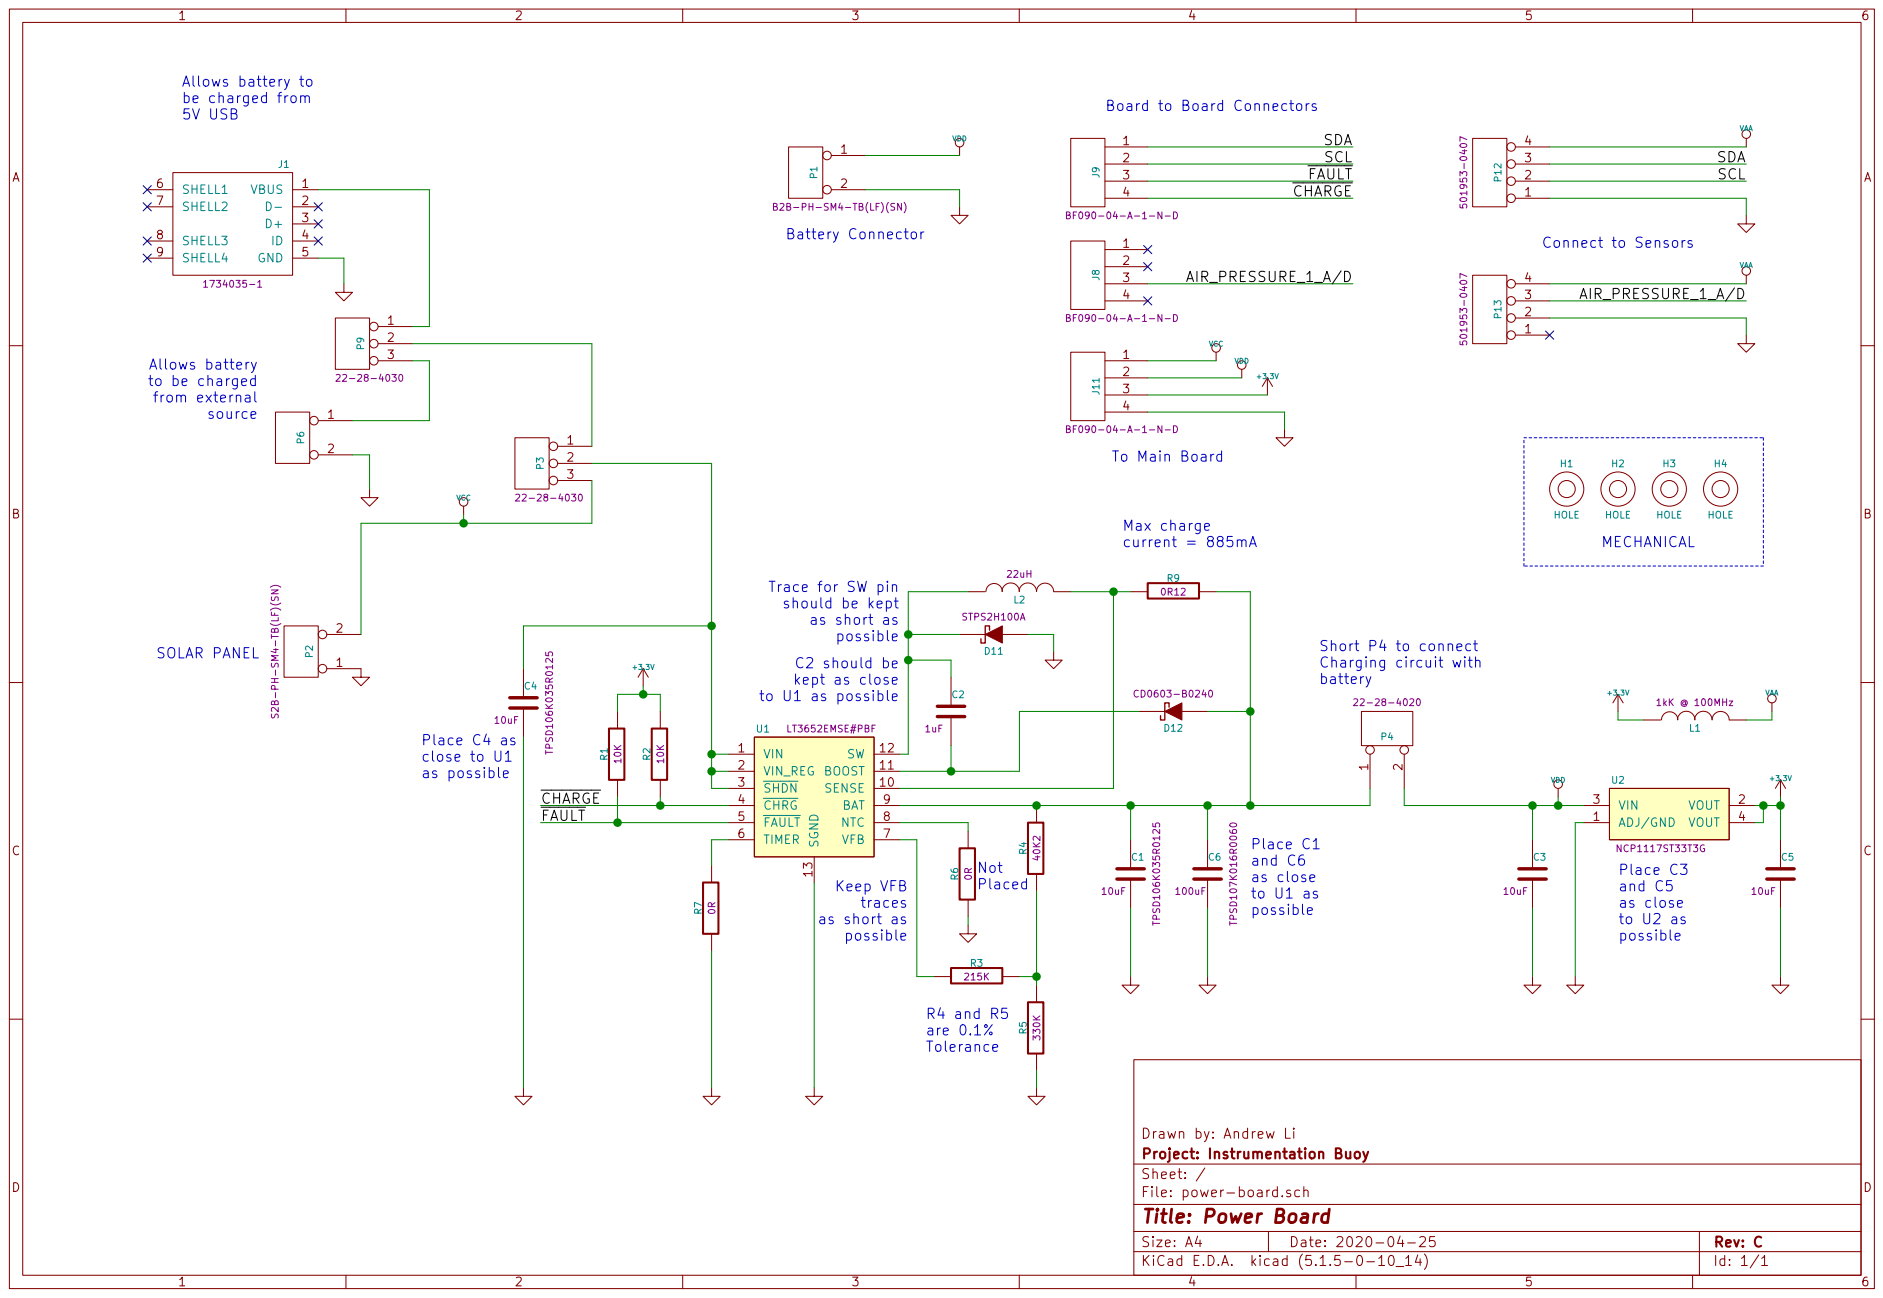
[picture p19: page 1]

Board to Board Connectors

CHARGE

VAA H4 HOLE H3 HOLE H2 HOLE H1 HOLE D11 STPS2H100A

current = 885mA Not Placed R4 and R5

Trace for SW pin
should be kept as short as possible

traces as short as possible

File: power-board.sch Sheet: / Project: Instrumentation Buoy

Id: 1/1 Title: Power Board

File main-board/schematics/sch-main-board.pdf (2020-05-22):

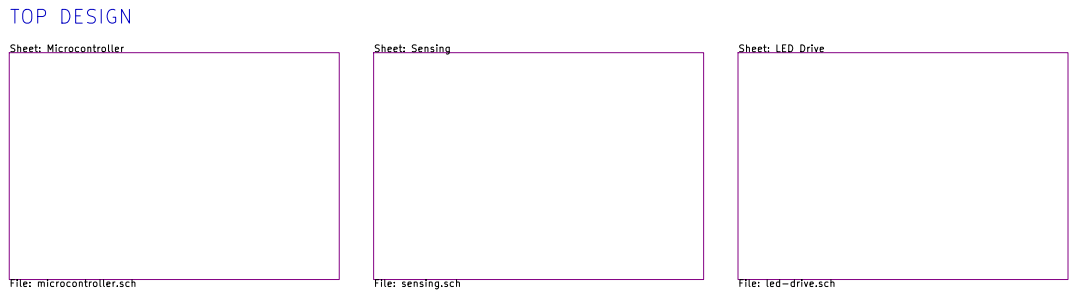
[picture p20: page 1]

Drawn by: Andrew Li
File: main-board.sch Sheet: / Project: Instrumentation Buoy V1

Id: 1/4 Title: Main Board

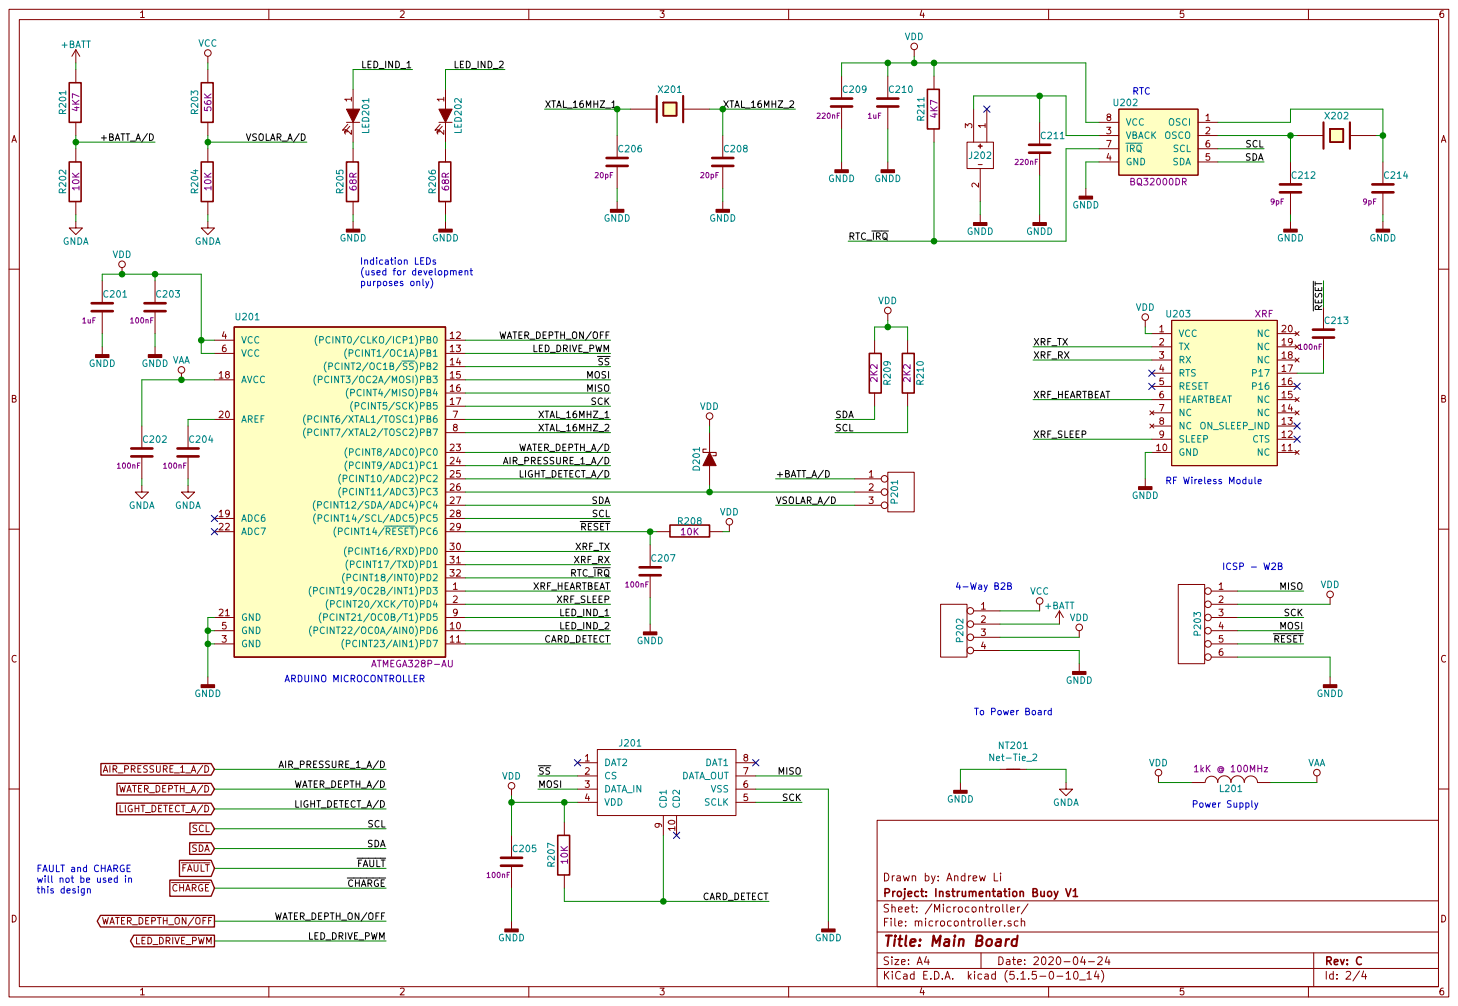
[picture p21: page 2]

VDD
ICSP - W2B RF Wireless Module RTC
RTC_IRQ

FAULT and CHARGE will not be used in

File: microcontroller.sch Sheet: /Microcontroller/ Project: Instrumentation Buoy V1

Id: 2/4 Title: Main Board

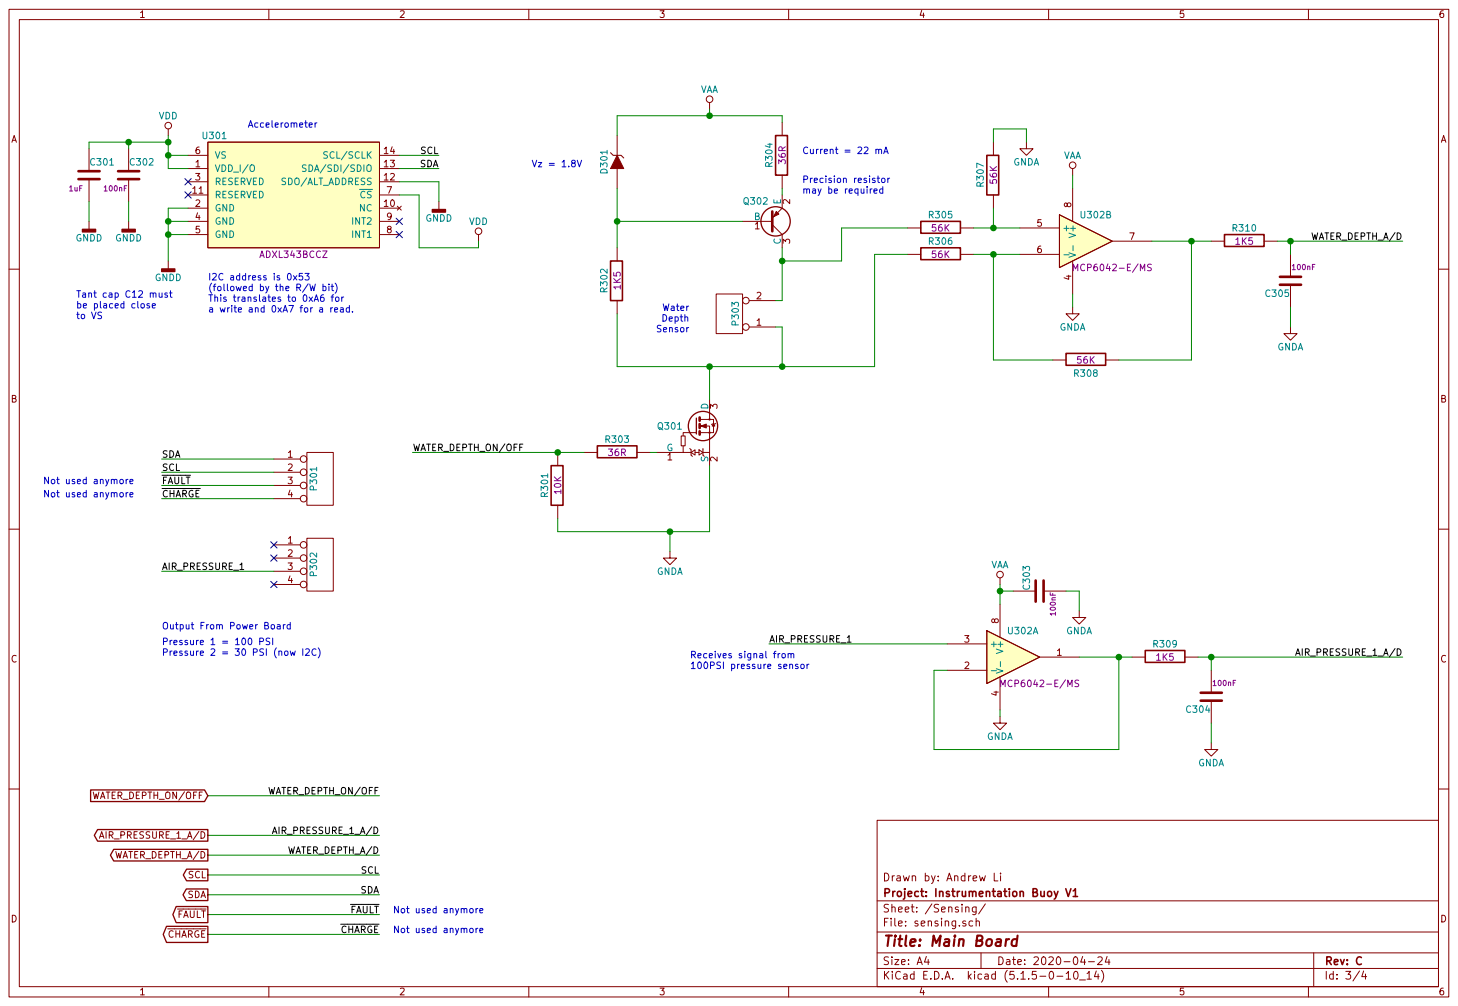
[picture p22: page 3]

Output From Power Board Pressure 1 = 100 PSI Pressure 2 = 30 PSI (now I2C)

Drawn by: Andrew Li
Project: Instrumentation Buoy V1
Sheet: /Sensing/
File: sensing.sch
Id: 3/4 Title: Main Board

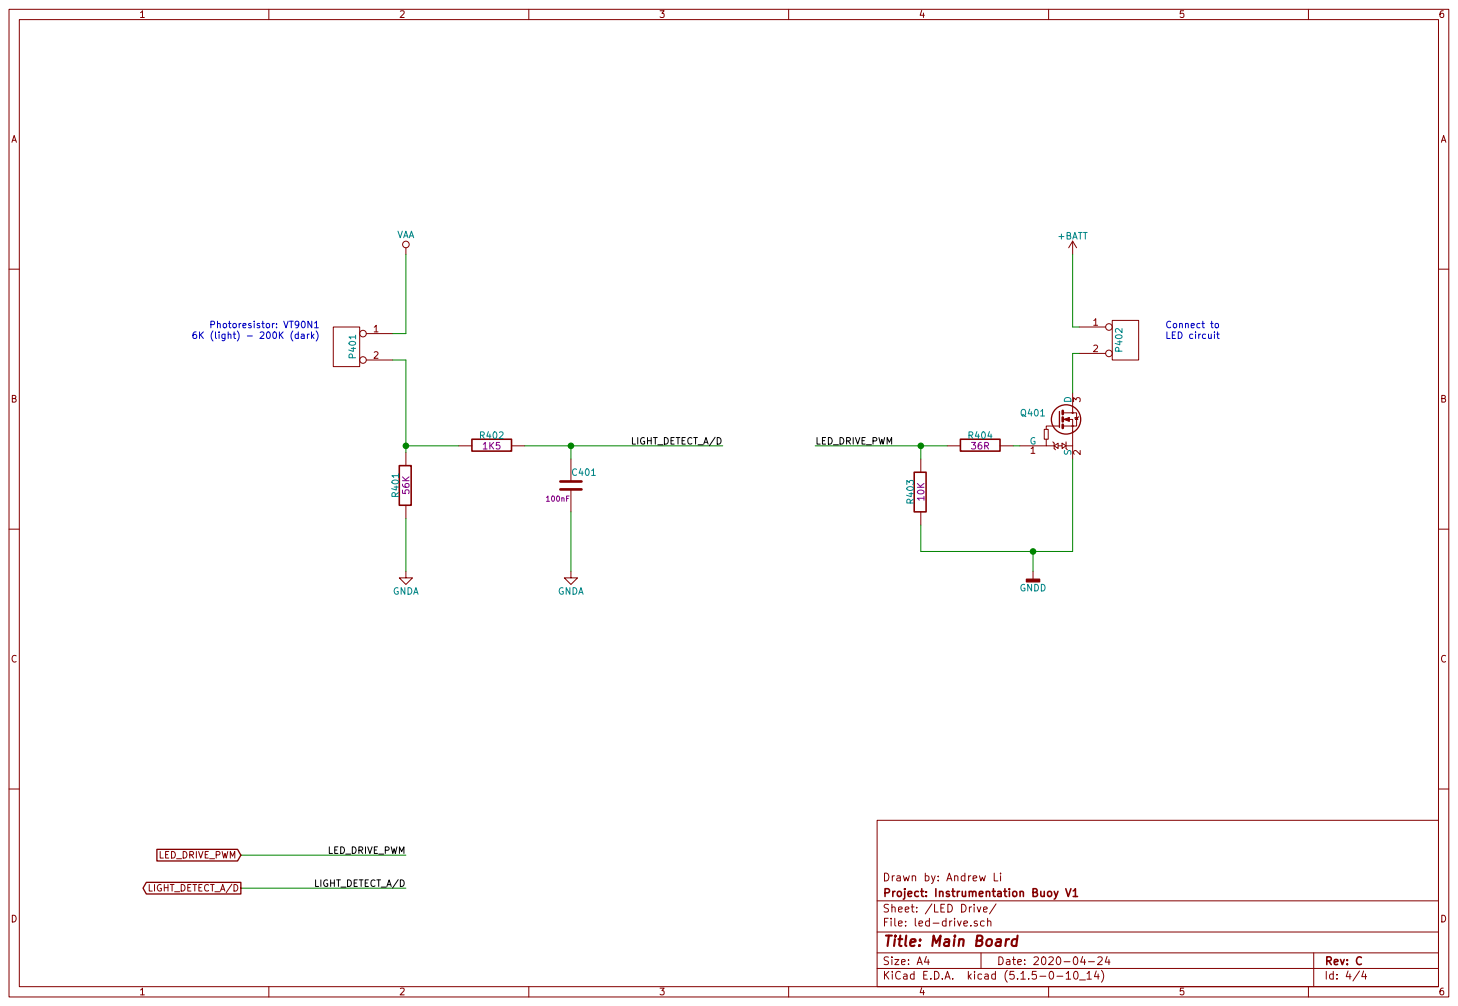
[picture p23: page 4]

Drawn by: Andrew Li R404

File: led-drive.sch Sheet: /LED Drive/ Project: Instrumentation Buoy V1

Id: 4/4 Title: Main Board

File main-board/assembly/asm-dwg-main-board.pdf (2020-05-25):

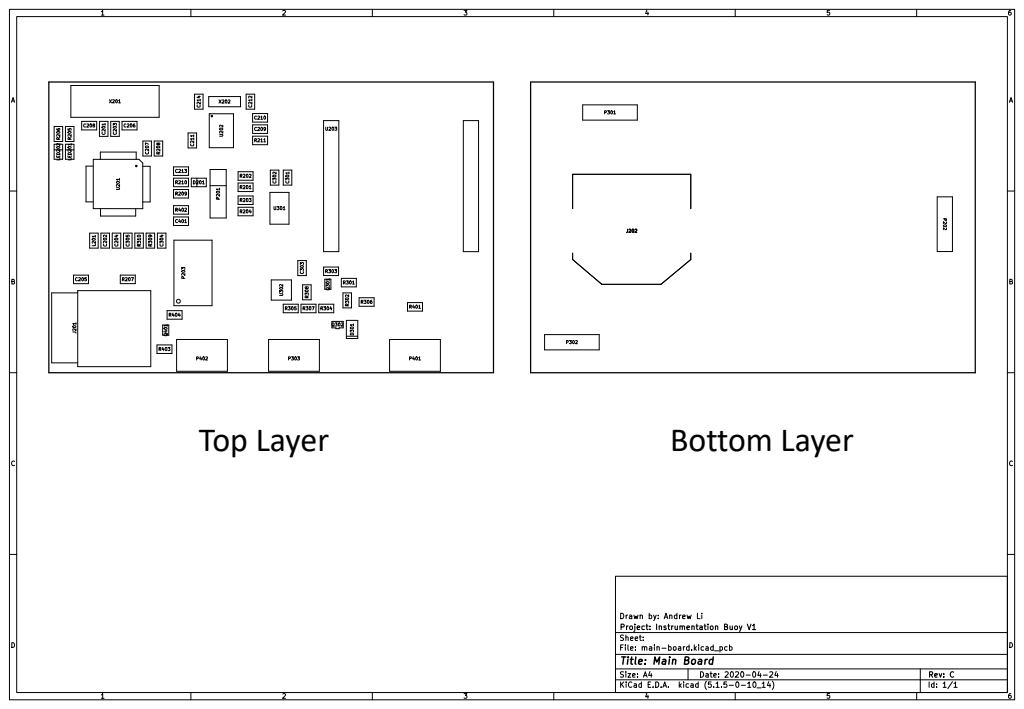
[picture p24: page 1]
Top Layer; Bottom Layer

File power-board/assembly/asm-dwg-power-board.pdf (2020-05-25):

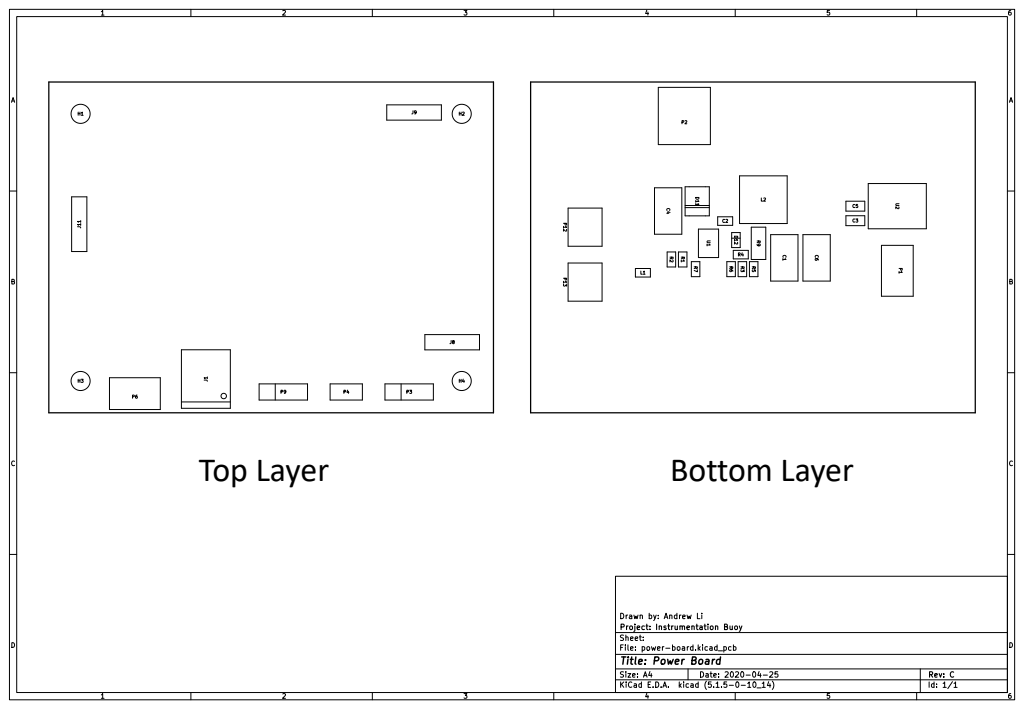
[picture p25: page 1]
Top Layer; Bottom Layer

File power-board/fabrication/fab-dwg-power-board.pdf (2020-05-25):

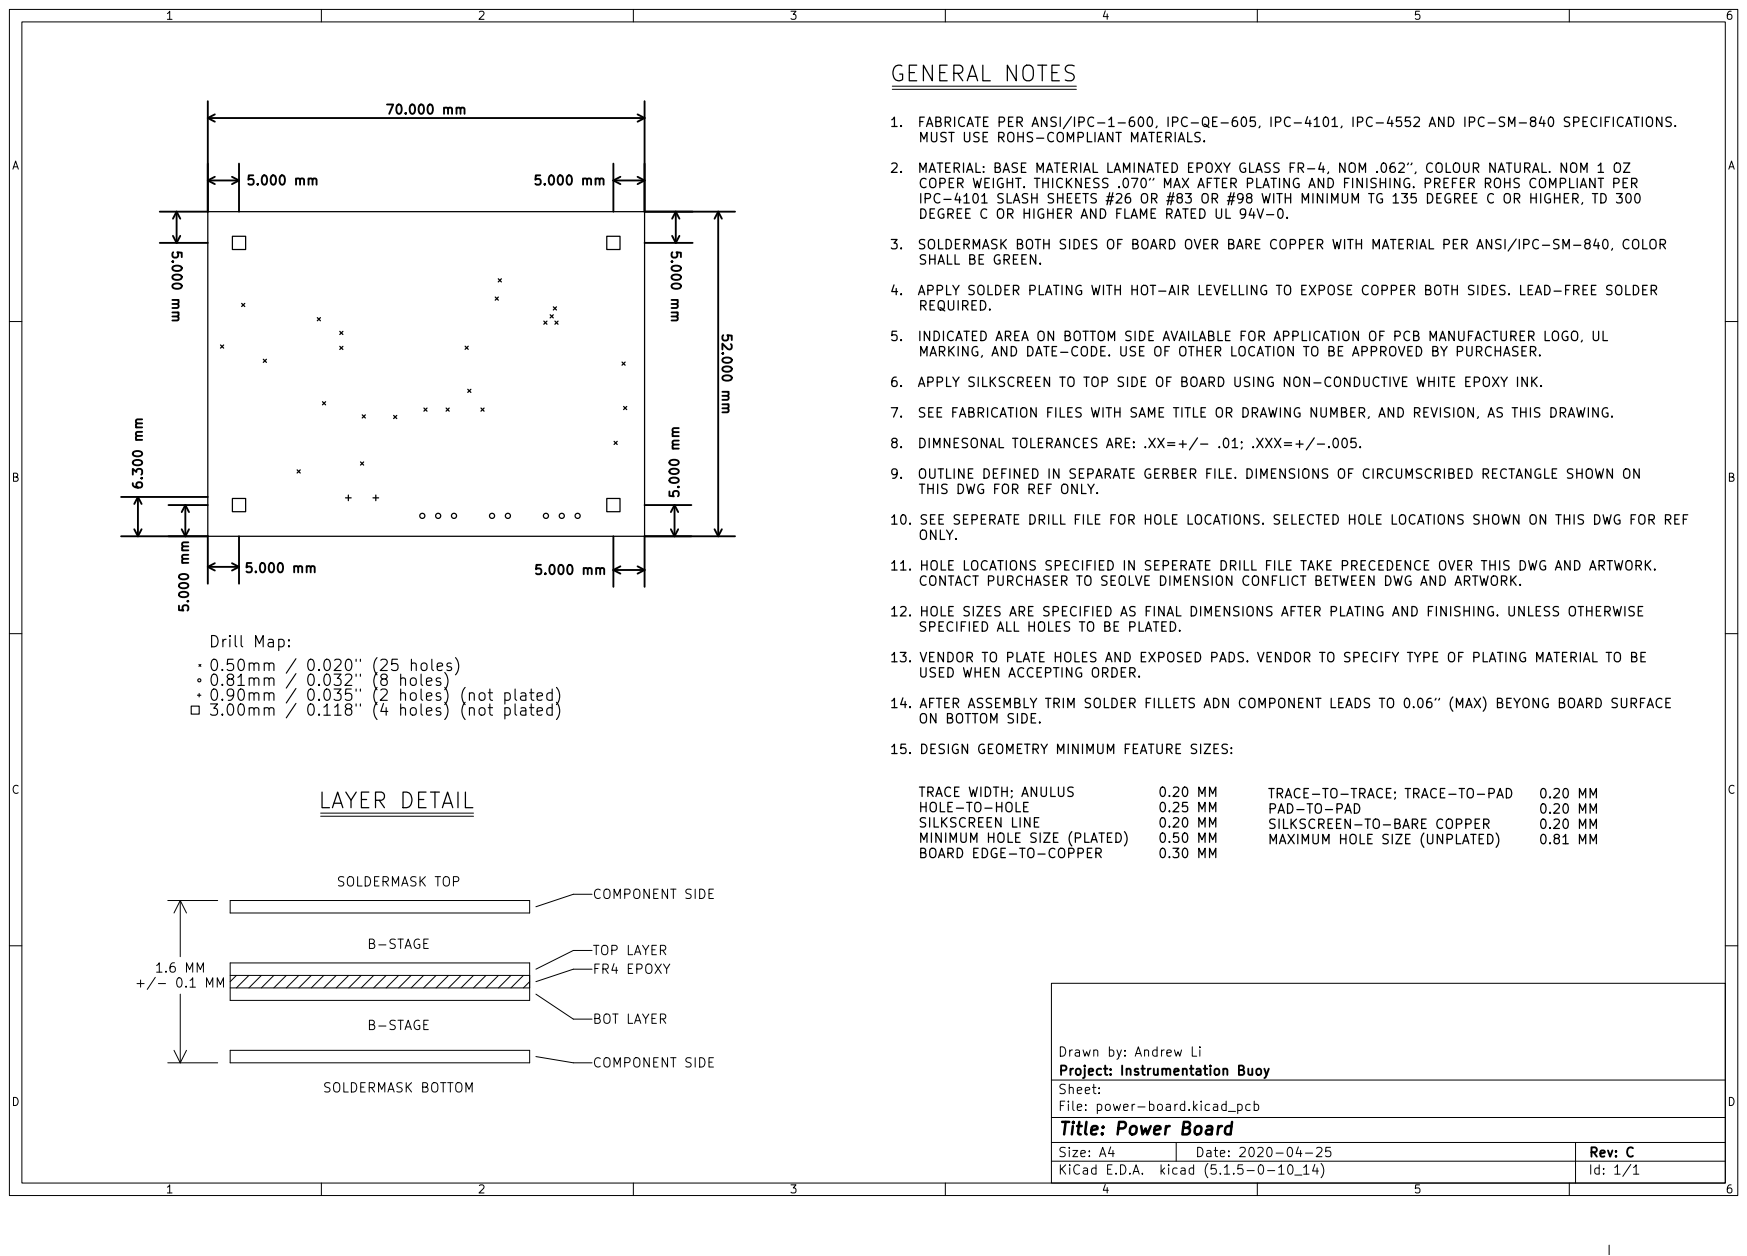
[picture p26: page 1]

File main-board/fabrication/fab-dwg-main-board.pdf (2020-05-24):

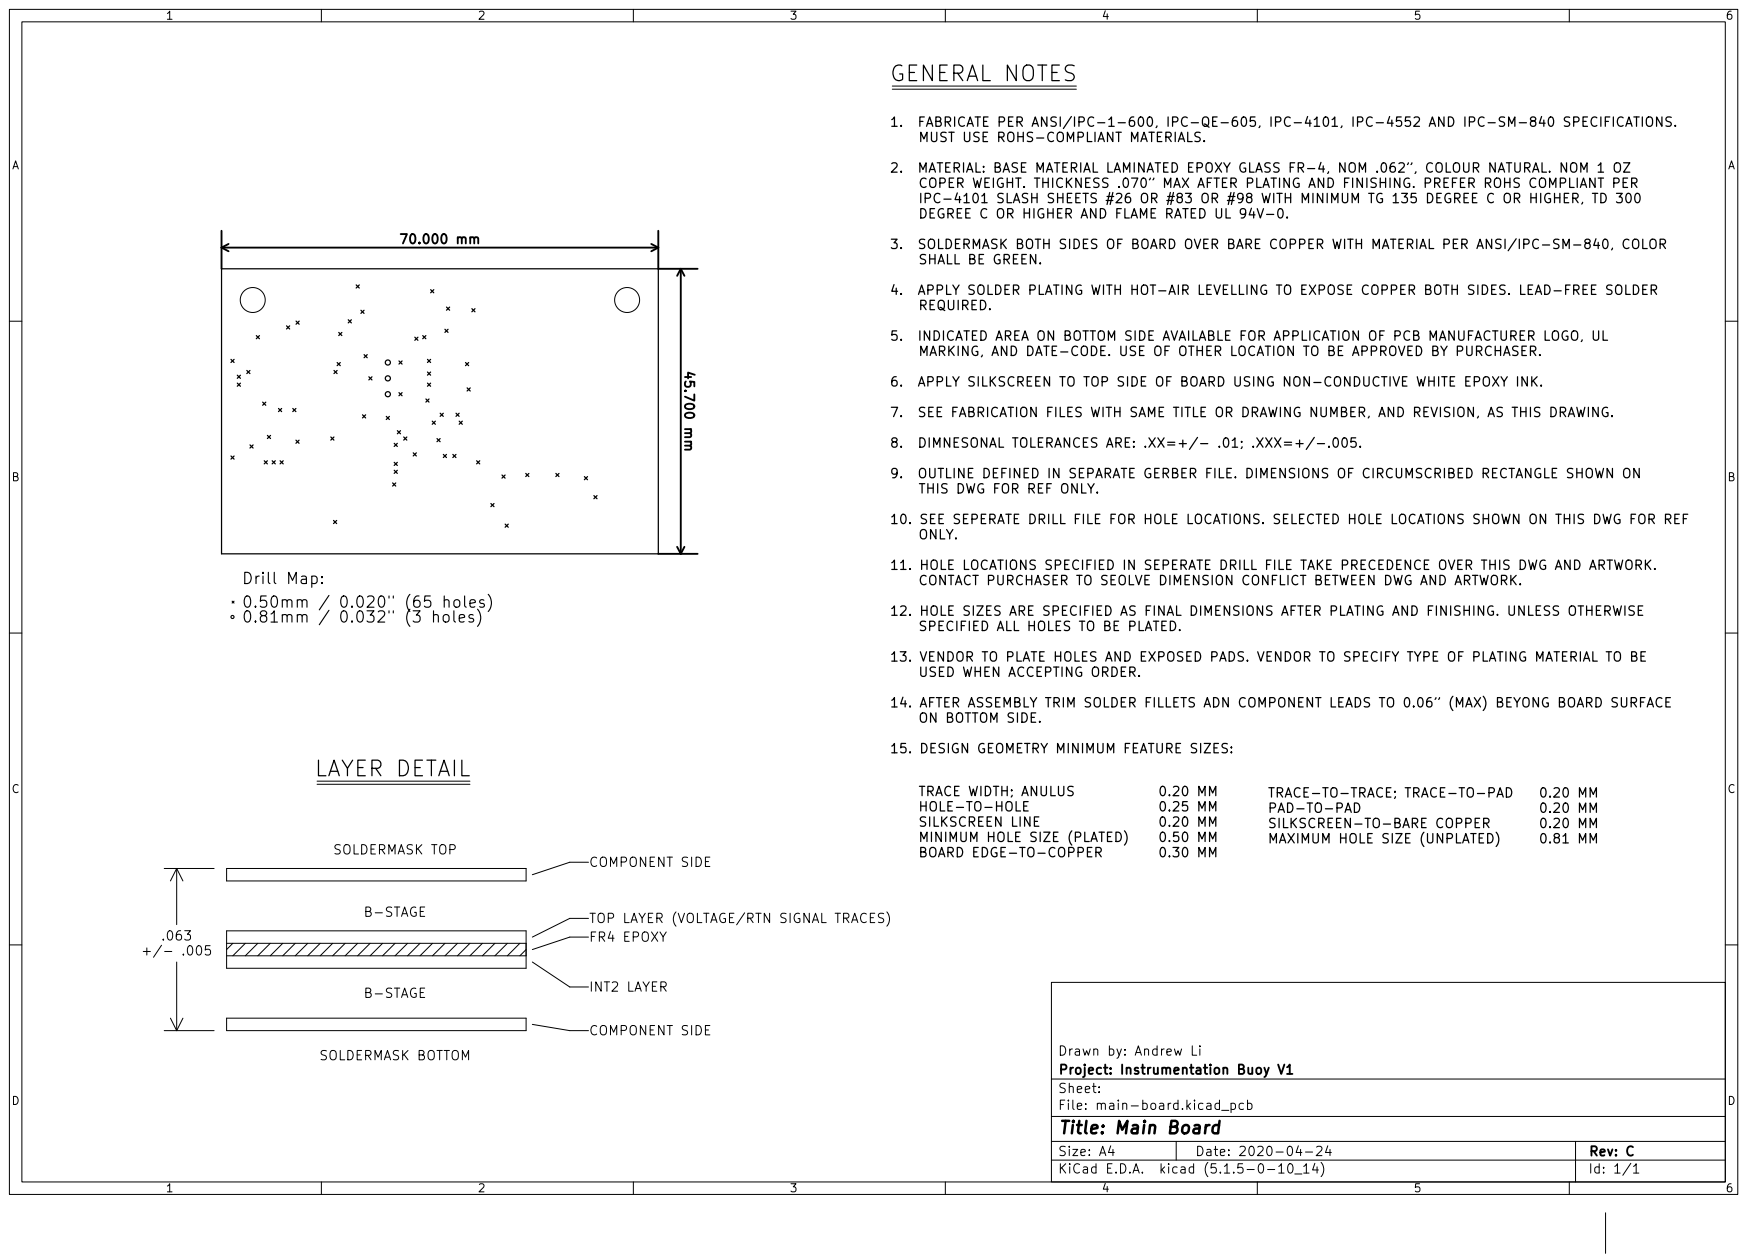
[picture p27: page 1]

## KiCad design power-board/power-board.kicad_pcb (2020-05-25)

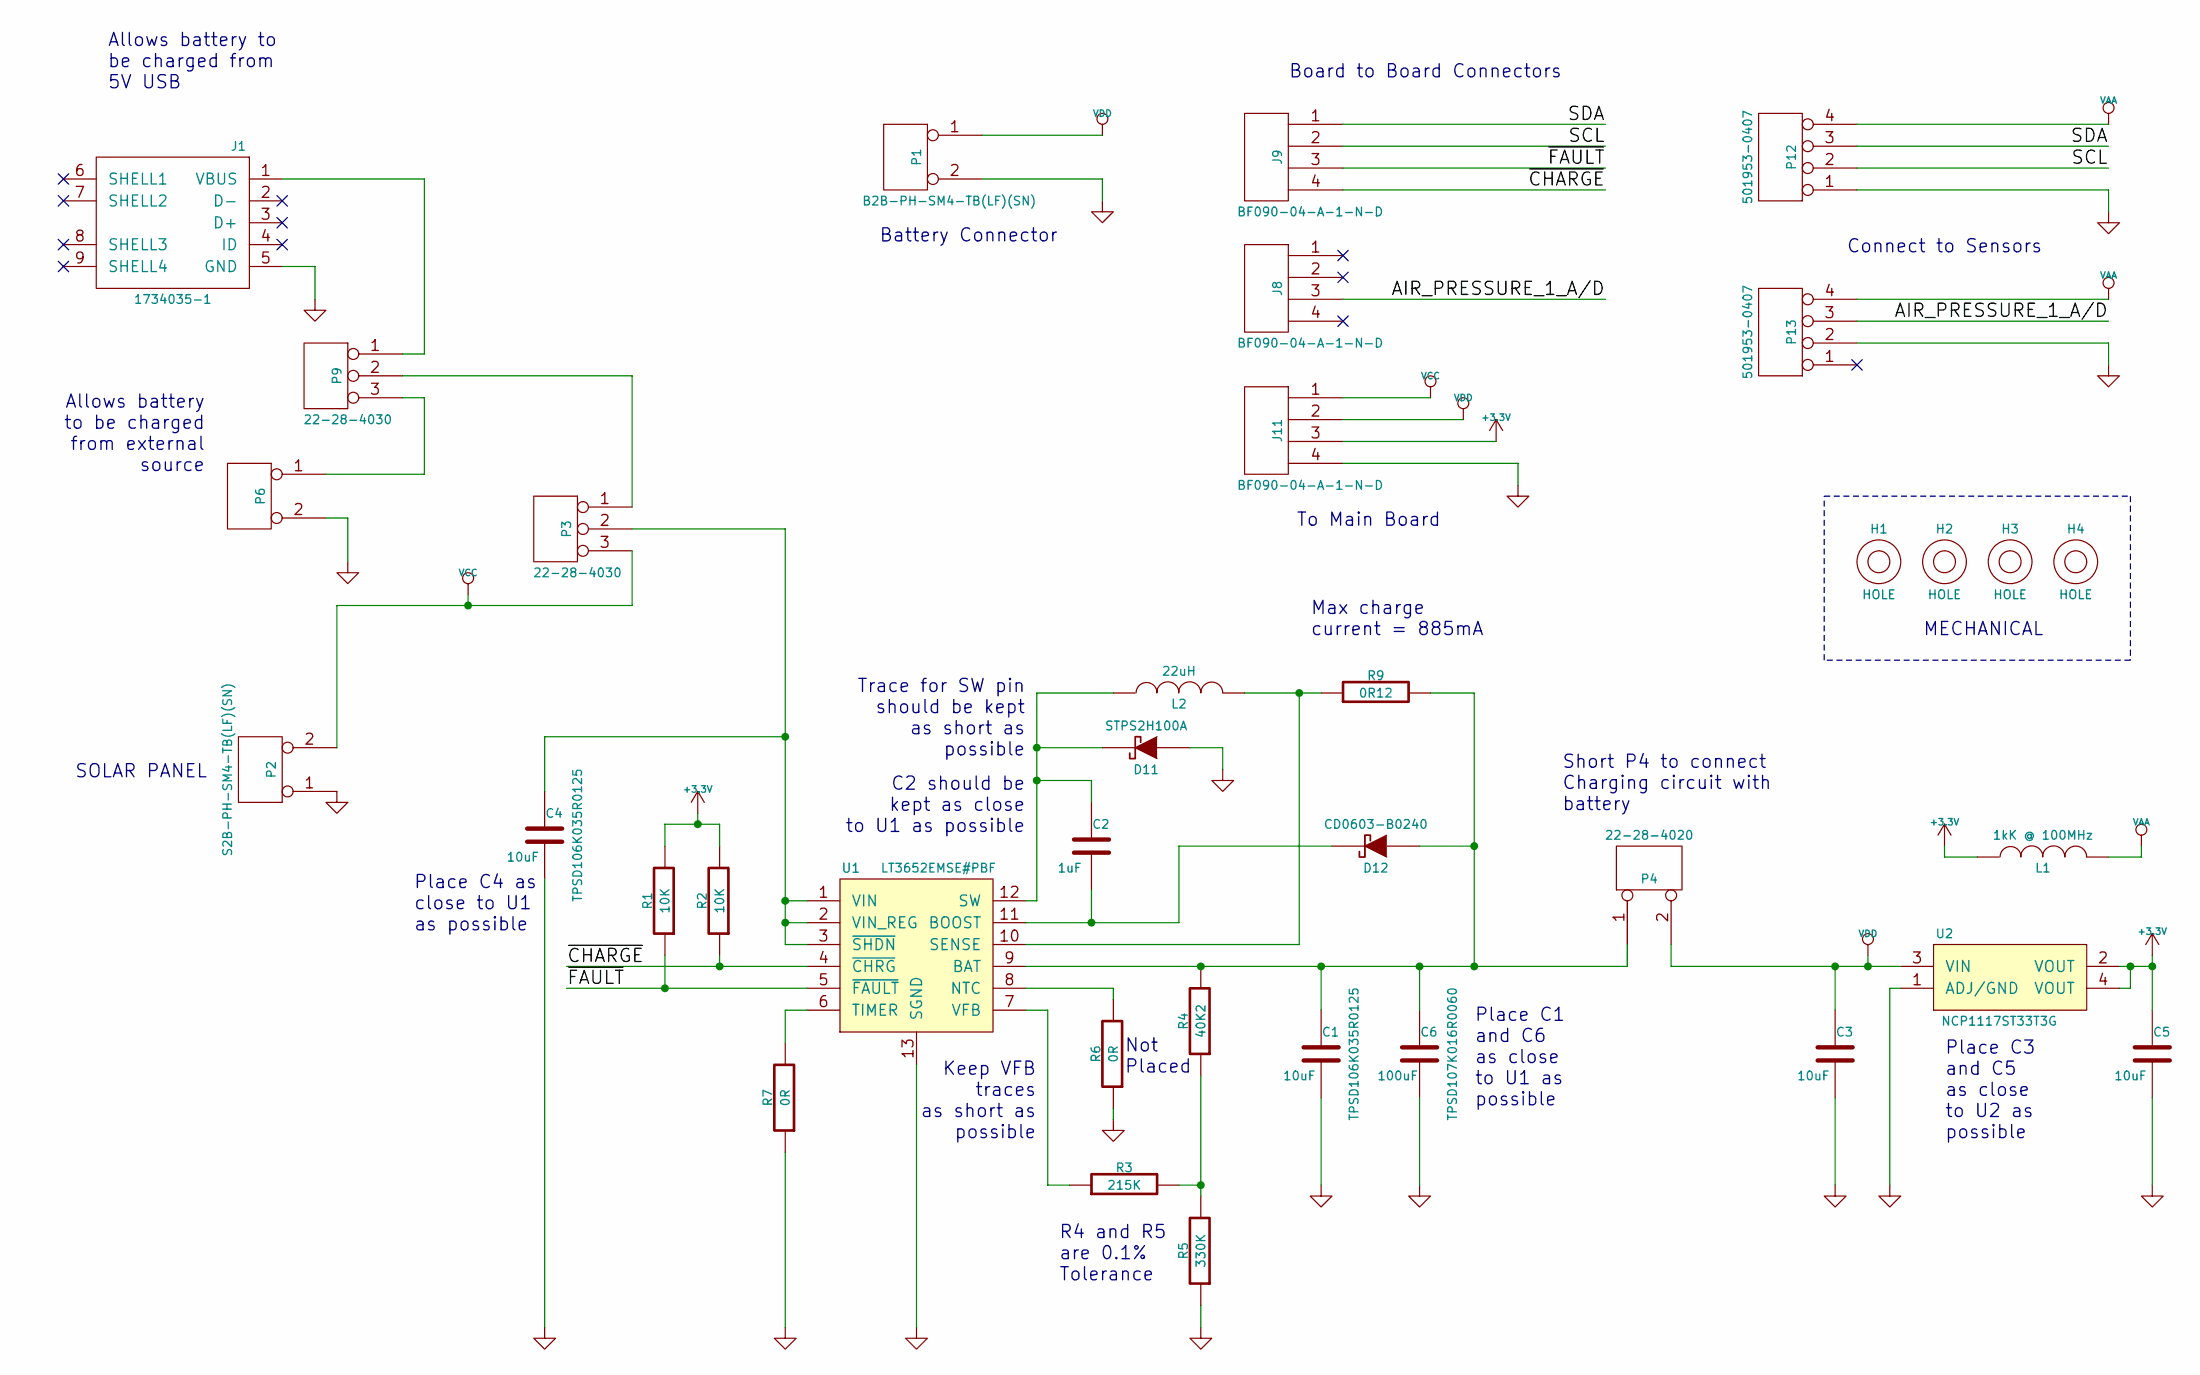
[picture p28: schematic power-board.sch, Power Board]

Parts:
C1, C4: ECS00053; EC2917; Manfacturer Part Number TPSD106K035R0125
C2: ECS00052; EC0603_C; Manfacturer Part Number GRM188R61H105KAALD
C3, C5: ECS00050; EC0805; Manfacturer Part Number GRM21BR61A106KE19L
C6: ECS00054; EC2917; Manfacturer Part Number TPSD107K016R0060
D11: ECS00095; ECDO-214AC(SMA); Manufacturer Part Number STPS2H100A
D12: ECS00037; EC0603_DIODE; Manufacturer Part Number CD0603-B0240
H1, H2, H3, H4: HOLE; HOLE_3.0MM
J1: ECS00066; ECUSBMINIB; Manufacturer Part Number 1734035-1
J8, J9, J11: ECS00059; ECS00059F; Manufacturer Part Number BF090-04-A-1-N-D
L1: ECS00074; EC0603_L; Manufacturer Part Number BLM18TG102TN1D
L2: ECS00071; ECS00071F; Manufacturer Part Number 46223C
P1, P6: ECS00067; ECS00067F; Manufacturer Part Number B2B-PH-SM4-TB(LF)(SN)
P2: ECS00007; ECS00007F; Manufacturer Part Number S2B-PH-SM4-TB(LF)(SN)
P3, P9: ECS00013; ECS00013F; Manufacturer Part Number 22-28-4030
P4: ECS00004; ECS00004F; Manufacturer Part Number 22-28-4020
P12, P13: ECS00068; ECS00068F; Manufacturer Part Number 501953-0407
R1, R2: ECS00045; EC0603; Manufacturer Part Number ERJ3GEYJ103V
R3: ECS00046; EC0603; Manufacturer Part Number ERJ3EKF2153V
R4: ECS00048; EC0603; Manufacturer Part Number ERA3ARB4022V
R5: ECS00047; EC0603; Manufacturer Part Number ERJ3EKF3303V
R6, R7: ECS00058; EC0603; Manufacturer Part Number ERJ3GEY0R00V
R9: ECS00055; EC1206; Manufacturer Part Number CRL1206-FW-R120ELF
U1: ECS00043; ECMSOP-12D; Manufacturer Part Number LT3652EMSE#PBF
U2: ECS00036; ECSOT223; Manufacturer Part Number NCP1117ST33T3G

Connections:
+3V3: C5.1, J11.3, L1.1, R1.2, R2.2, U2.2 (VOUT), U2.4 (VOUT)
/AIR_PRESSURE_1_A/D: J8.3, P13.3
/SCL: J9.2, P12.2
/SDA: J9.1, P12.3
/~CHARGE: J9.4, R2.1, U1.4 (~CHRG)
/~FAULT: J9.3, R1.1, U1.5 (~FAULT)
GND: C1.2, C3.2, C4.2, C5.2, C6.2, D11.1 (A), J1.5 (GND), J11.4, P1.2 (PM), P2.1, P6.2 (PM), P12.1, P13.2, R5.1, R6.1, R7.1, U1.13 (SGND), U2.1 (ADJ/GND)
unnamed: C1.1, C6.1, D12.1 (A), P4.1, R4.2, R9.2, U1.9 (BAT)
unnamed: C2.1, D11.2 (K), L2.1, U1.12 (SW)
unnamed: C2.2, D12.2 (K), U1.11 (BOOST)
unnamed: C4.1, P3.2 (PM), U1.1 (VIN), U1.2 (VIN_REG), U1.3 (~SHDN)
unnamed: J1.1 (VBUS), P9.1
unnamed: L2.2, R9.1, U1.10 (SENSE)
unnamed: P3.1, P9.2 (PM)
unnamed: P6.1, P9.3
unnamed: R3.1, U1.7 (VFB)
unnamed: R3.2, R4.1, R5.2
unnamed: R6.2, U1.8 (NTC)
unnamed: R7.2, U1.6 (TIMER)
VAA: L1.2, P12.4, P13.4
VCC: J11.1, P2.2 (PM), P3.3
VDD: C3.1, J11.2, P1.1, P4.2 (PM), U2.3 (VIN)

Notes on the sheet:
Battery Connector
R4 and R5 are 0.1% Tolerance
Not Placed
Max charge current = 885mA
Allows battery to be charged from 5V USB
Trace for SW pin should be kept as short as possible
Place C4 as close to U1 as possible
Place C1 and C6 as close to U1 as possible
Place C3 and C5 as close to U2 as possible
C2 should be kept as close to U1 as possible
Keep VFB traces as short as possible
Allows battery to be charged from external source
To Main Board
MECHANICAL
Connect to Sensors
Board to Board Connectors
SOLAR PANEL
Short P4 to connect Charging circuit with battery

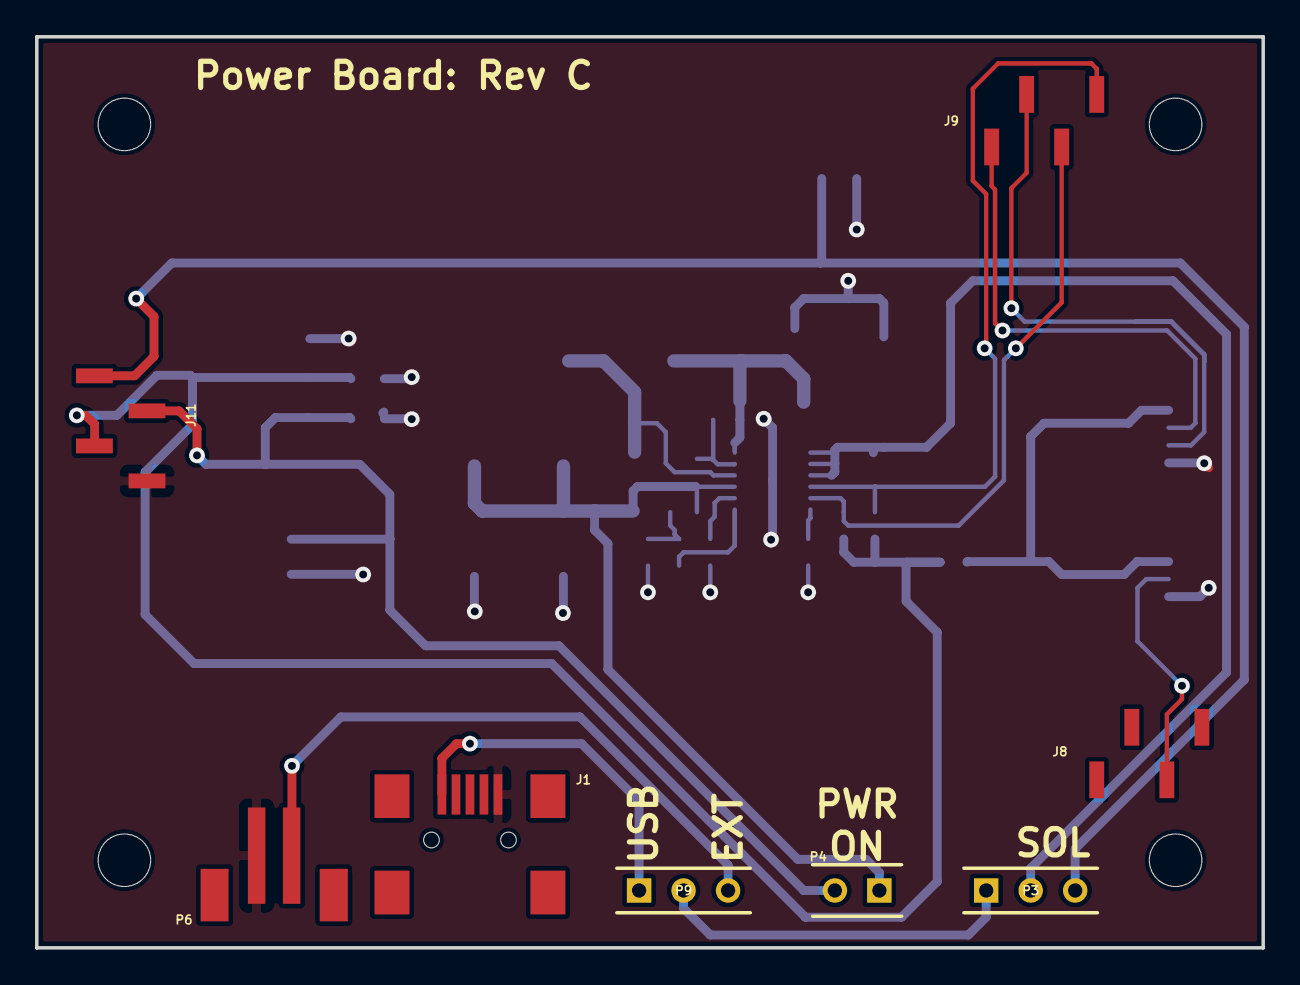
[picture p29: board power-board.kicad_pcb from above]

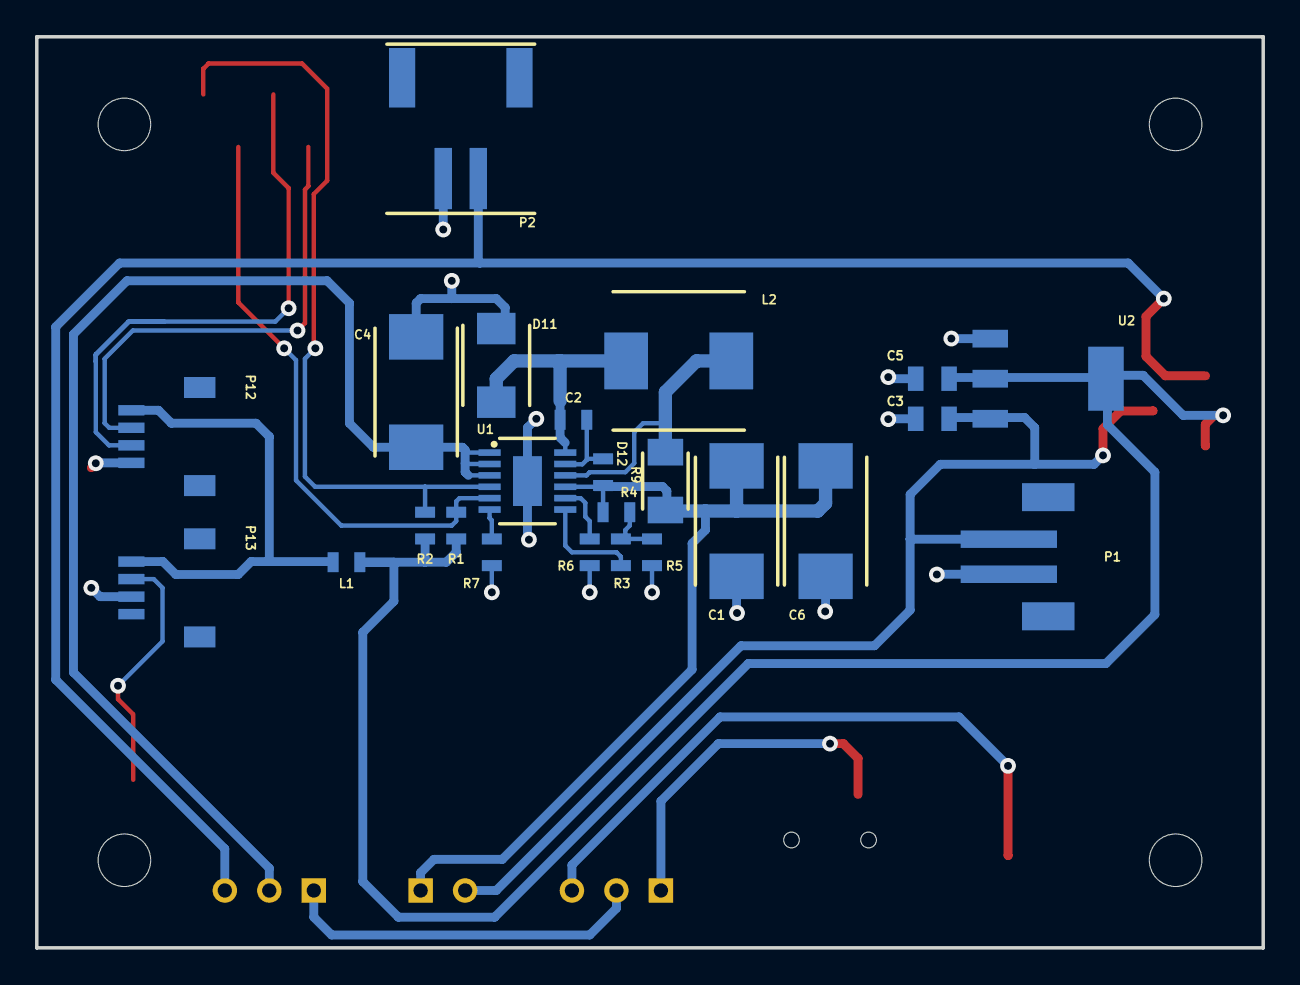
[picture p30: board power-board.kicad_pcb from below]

Board: 2 copper layers, 70.0 x 52.0 mm, 36 parts (24 on the bottom side), 22 nets.

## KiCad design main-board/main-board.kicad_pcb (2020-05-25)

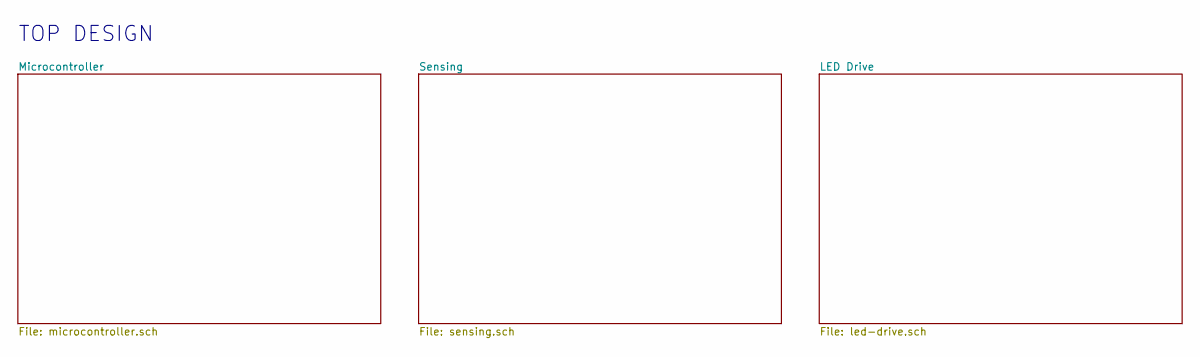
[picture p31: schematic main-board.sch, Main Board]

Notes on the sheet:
TOP DESIGN

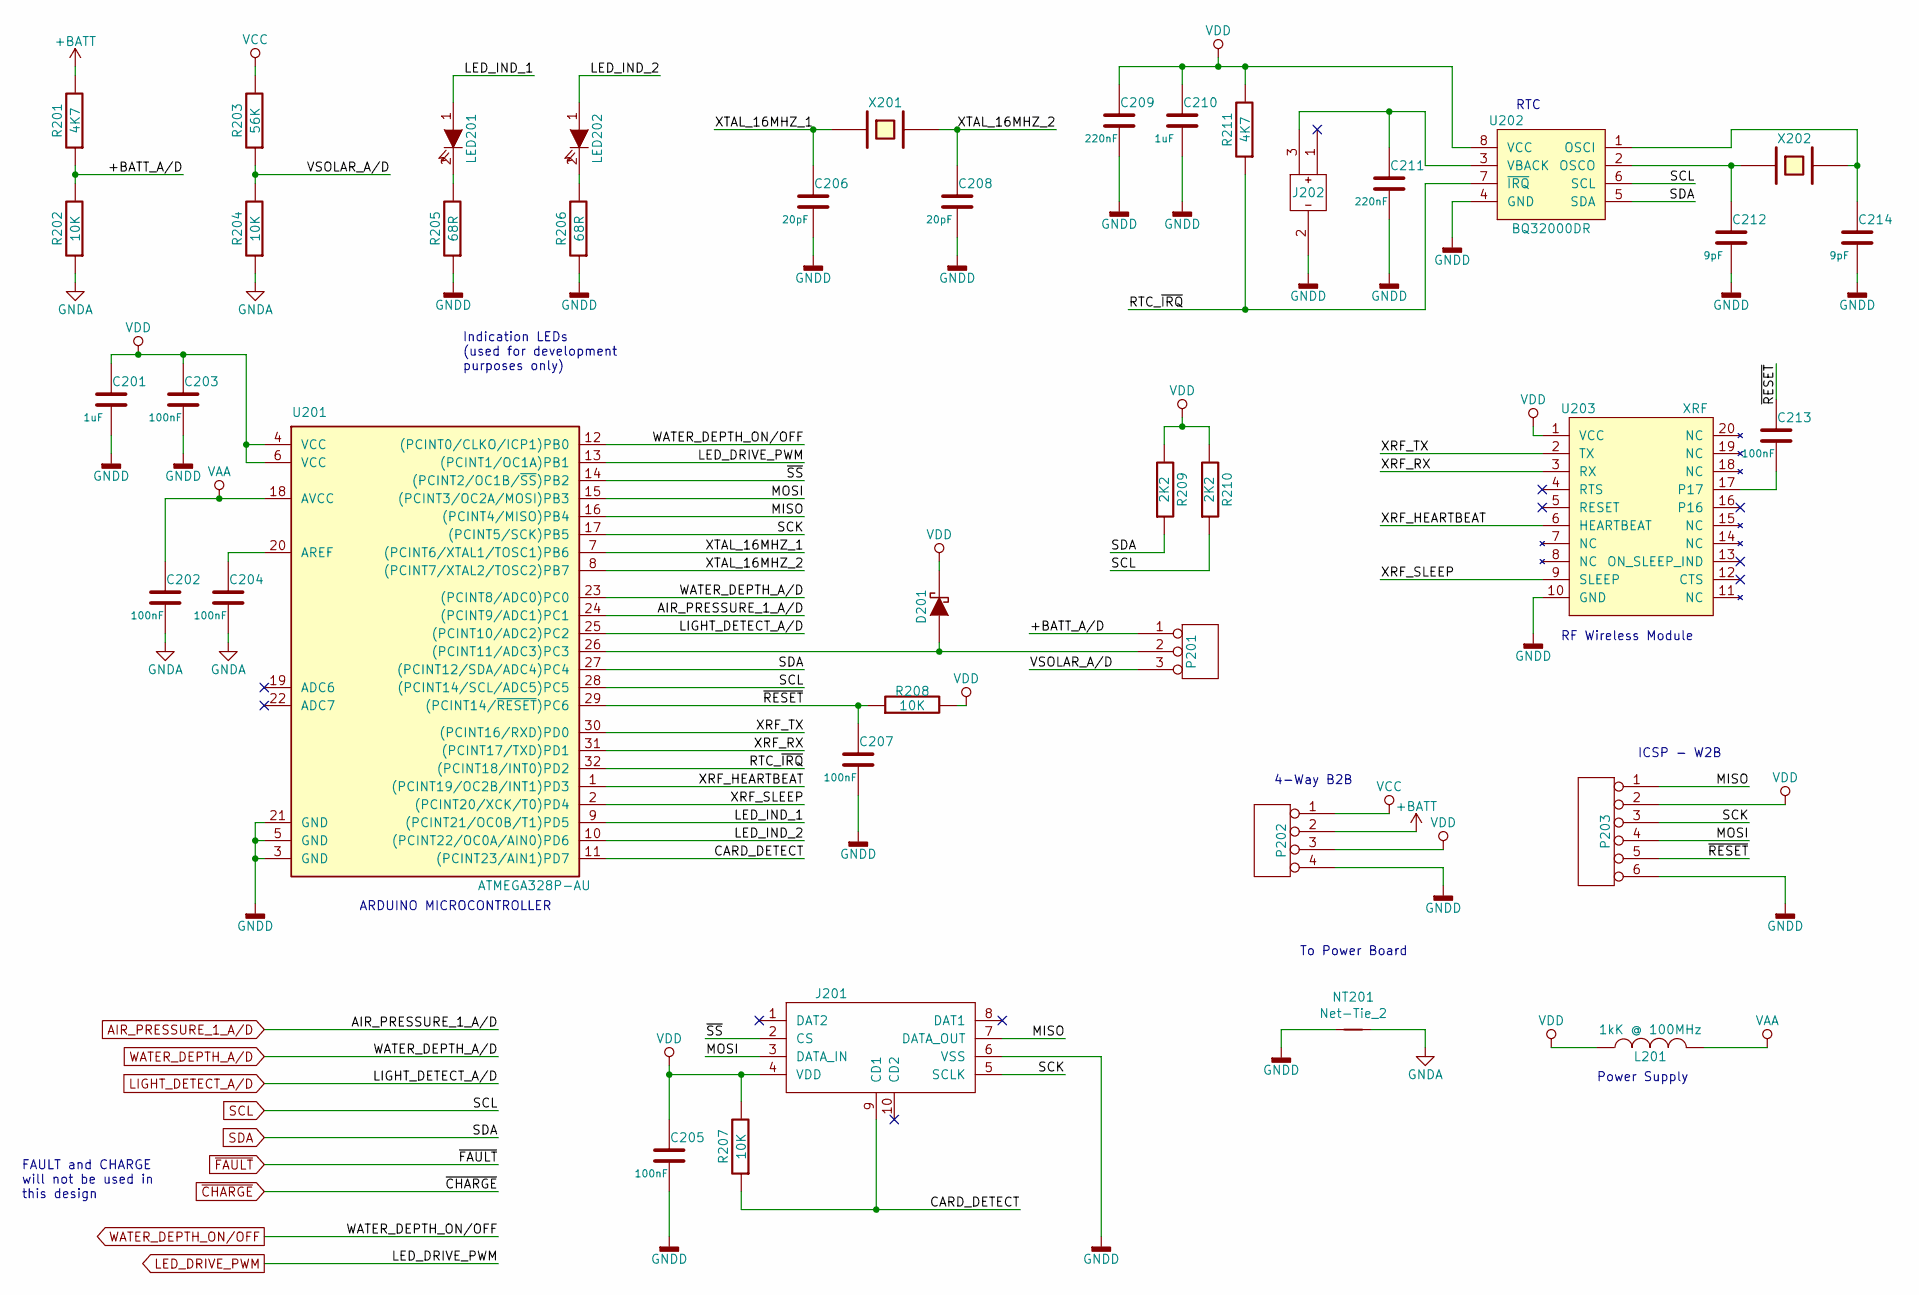
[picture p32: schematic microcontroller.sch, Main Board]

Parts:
C201, C210: ECS00052; EC0603_C; Manfacturer Part Number GRM188R61H105KAALD
C202, C203, C204, C205, C207, C213: ECS00075; EC0603_C; Manfacturer Part Number GRM188R71C104KA01D
C206, C208: ECS00077; EC0603_C; Manfacturer Part Number C0603C200J5GACTU
C209, C211: ECS00078; EC0603_C; Manfacturer Part Number GRM188R71A224KA01D
C212, C214: ECS00076; EC0603_C; Manfacturer Part Number MC0603N9R0D500CT
D201: ECS00037; EC0603_DIODE; Manufacturer Part Number CD0603-B0240
J201: ECS00065; ECS00065F; Manufacturer Part Number 114-00841-68
J202: ECS00094; ECS00094F; Manufacturer Part Number BK-868
L201: ECS00074; EC0603_L; Manufacturer Part Number BLM18TG102TN1D
LED201, LED202: ECS00035; EC0603_LED; Manufacturer Part Number SML-310VTT86L
NT201: Net-Tie_2; NetTie-2_SMD_Pad0.5mm
P201: ECS00013; ECS00013F; Manufacturer Part Number 22-28-4030
P202: ECS00029; ECS00029F; Manufacturer Part Number BF040-04A-B2-0400-0260-0483-LD
P203: ECS00015; ECS00015F; Manufacturer Part Number 87437-0673
R201, R211: ECS00086; EC0603; Manufacturer Part Number CR0603-FX-4701ELF
R202, R204, R207, R208: ECS00045; EC0603; Manufacturer Part Number ERJ3GEYJ103V
R203: ECS00085; EC0603; Manufacturer Part Number CRCW060356K0FKEAHP
R205, R206: ECS00081; EC0603; Manufacturer Part Number CR0603-FX-68R0ELF
R209, R210: ECS00084; EC0603; Manufacturer Part Number MC0063W060312K2
U201: ECS00017; ECTQFP-32; Manufacturer Part Number ATMEGA328P-AU
U202: ECS00032; ECSOIC-8; Manufacturer Part Number BQ32000DR
U203: ECA00002; ECA00002F; Manufacturer Part Number XRF
X201: ECS00006; ECS00006F; Manufacturer Part Number FOXSDLF/160-20
X202: ECS00005; ECS00005F; Manufacturer Part Number CC4V-T1A 32.768KHZ +-20PPM 9PF

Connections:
+BATT: P202.2, R201.2; also elsewhere on the board
/Microcontroller/+BATT_A/D: P201.1, R201.1, R202.2
/Microcontroller/CARD_DETECT: J201.9 (CD1), R207.1, U201.11 ((PCINT23/AIN1)PD7)
/Microcontroller/LED_IND_1: LED201.1 (A), U201.9 ((PCINT21/OC0B/T1)PD5)
/Microcontroller/LED_IND_2: LED202.1 (A), U201.10 ((PCINT22/OC0A/AIN0)PD6)
/Microcontroller/MISO: J201.7 (DATA_OUT), P203.1, U201.16 ((PCINT4/MISO)PB4)
/Microcontroller/MOSI: J201.3 (DATA_IN), P203.4, U201.15 ((PCINT3/OC2A/MOSI)PB3)
/Microcontroller/RTC_~IRQ: R211.1, U201.32 ((PCINT18/INT0)PD2), U202.7 (~IRQ)
/Microcontroller/SCK: J201.5 (SCLK), P203.3, U201.17 ((PCINT5/SCK)PB5)
/Microcontroller/VSOLAR_A/D: P201.3, R203.1, R204.2
/Microcontroller/XRF_HEARTBEAT: U201.1 ((PCINT19/OC2B/INT1)PD3), U203.6 (HEARTBEAT)
/Microcontroller/XRF_RX: U201.31 ((PCINT17/TXD)PD1), U203.3 (RX)
/Microcontroller/XRF_SLEEP: U201.2 ((PCINT20/XCK/T0)PD4), U203.9 (SLEEP)
/Microcontroller/XRF_TX: U201.30 ((PCINT16/RXD)PD0), U203.2 (TX)
/Microcontroller/XTAL_16MHZ_1: C206.1, U201.7 ((PCINT6/XTAL1/TOSC1)PB6), X201.1
/Microcontroller/XTAL_16MHZ_2: C208.1, U201.8 ((PCINT7/XTAL2/TOSC2)PB7), X201.2
/Microcontroller/~RESET: C207.1, C213.1, P203.5, R208.1, U201.29 ((PCINT14/~RESET~)PC6)
/Microcontroller/~SS: J201.2 (CS), U201.14 ((PCINT2/OC1B/~SS~)PB2)
AIR_PRESSURE_1_A/D: U201.24 ((PCINT9/ADC1)PC1); also elsewhere on the board
GNDA: C202.2, C204.2, NT201.2, R202.1, R204.1; also elsewhere on the board
GNDD: C201.2, C203.2, C205.2, C206.2, C207.2, C208.2, C209.2, C210.2, C211.2, C212.2, C214.2, J201.6 (VSS), J202.2 (-), NT201.1, P202.4, P203.6, R205.1, R206.1, U201.3 (GND), U201.5 (GND), U201.21 (GND), U202.4 (GND), U203.10 (GND); also elsewhere on the board
LED_DRIVE_PWM: U201.13 ((PCINT1/OC1A)PB1); also elsewhere on the board
LIGHT_DETECT_A/D: U201.25 ((PCINT10/ADC2)PC2); also elsewhere on the board
unnamed: C204.1, U201.20 (AREF)
unnamed: C211.1, J202.3 (+), U202.3 (VBACK)
unnamed: C212.1, U202.2 (OSCO), X202.1
unnamed: C213.2, U203.17
unnamed: C214.1, U202.1 (OSCI), X202.2
unnamed: D201.1 (A), P201.2 (PM), U201.26 ((PCINT11/ADC3)PC3)
unnamed: LED201.2 (K), R205.2
unnamed: LED202.2 (K), R206.2
SCL: R210.1, U201.28 ((PCINT14/SCL/ADC5)PC5), U202.6 (SCL); also elsewhere on the board
SDA: R209.1, U201.27 ((PCINT12/SDA/ADC4)PC4), U202.5 (SDA); also elsewhere on the board
VAA: C202.1, L201.2, U201.18 (AVCC); also elsewhere on the board
VCC: P202.1, R203.2
VDD: C201.1, C203.1, C205.1, C209.1, C210.1, D201.2 (K), J201.4 (VDD), L201.1, P202.3, P203.2, R207.2, R208.2, R209.2, R210.2, R211.2, U201.4 (VCC), U201.6 (VCC), U202.8 (VCC), U203.1 (VCC); also elsewhere on the board
WATER_DEPTH_A/D: U201.23 ((PCINT8/ADC0)PC0); also elsewhere on the board
WATER_DEPTH_ON/OFF: U201.12 ((PCINT0/CLKO/ICP1)PB0); also elsewhere on the board

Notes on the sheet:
RTC
RF Wireless Module
ICSP - W2B
4-Way B2B
ARDUINO MICROCONTROLLER
To Power Board
Power Supply
Indication LEDs (used for development purposes only)
FAULT and CHARGE will not be used in this design

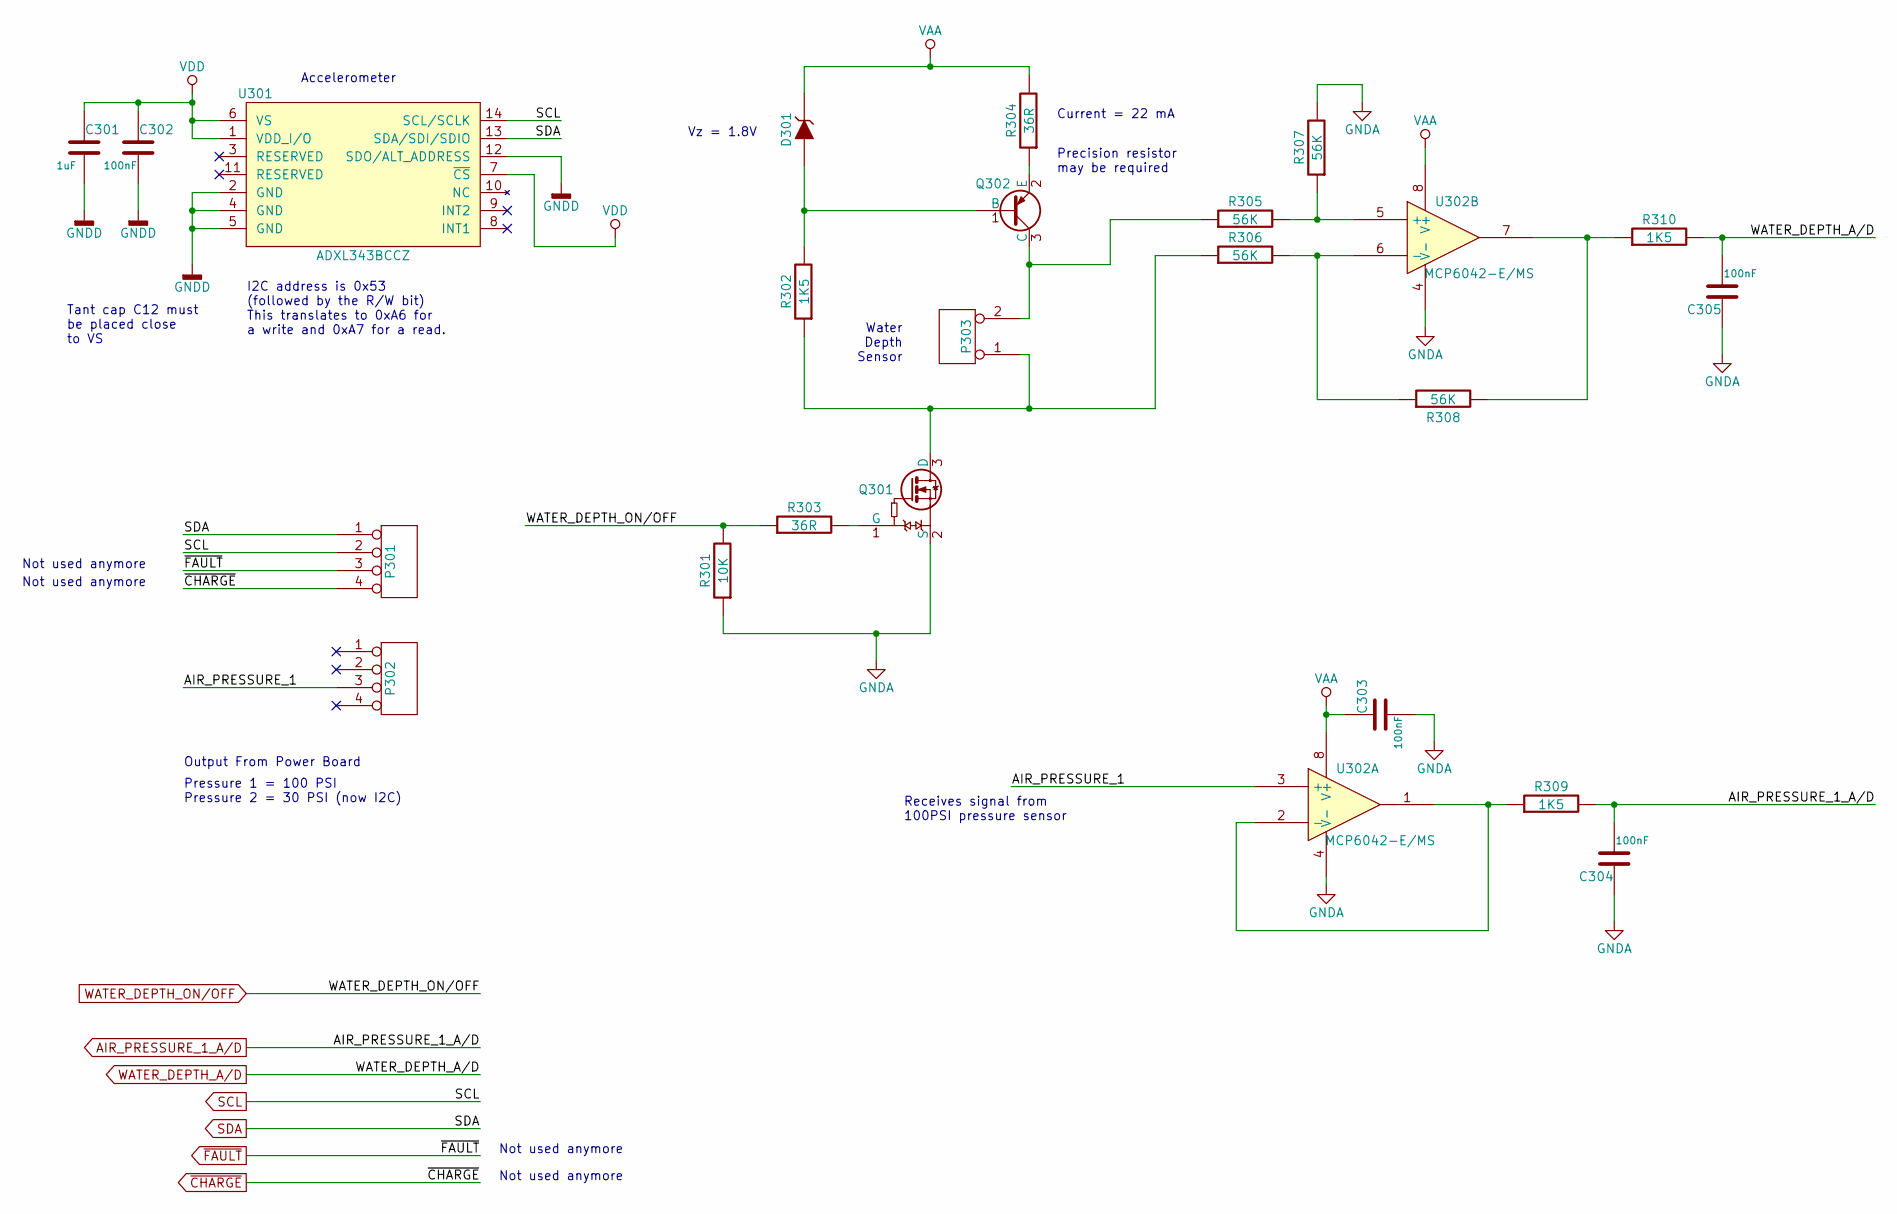
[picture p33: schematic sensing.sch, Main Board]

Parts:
C301: ECS00052; EC0603_C; Manfacturer Part Number GRM188R61H105KAALD
C302, C303, C304, C305: ECS00075; EC0603_C; Manfacturer Part Number GRM188R71C104KA01D
D301: ECS00072; ECS00072F; Manufacturer Part Number MMSZ4678T1G
P301, P302: ECS00029; ECS00029F; Manufacturer Part Number BF040-04A-B2-0400-0260-0483-LD
P303: ECS00067; ECS00067F; Manufacturer Part Number B2B-PH-SM4-TB(LF)(SN)
Q301: ECS00087; ECSOT416; Manufacturer Part Number NTA4153NT1G
Q302: ECS00073; ECSOT323; Manufacturer Part Number BC857BW,115
R301: ECS00045; EC0603; Manufacturer Part Number ERJ3GEYJ103V
R302, R309, R310: ECS00083; EC0603; Manufacturer Part Number CR0603-FX-1501ELF
R303, R304: ECS00080; EC0603; Manufacturer Part Number CRCW060336R0FKEA
R305, R306, R307, R308: ECS00085; EC0603; Manufacturer Part Number CRCW060356K0FKEAHP
U301: ECS00016; ECS00016F; Manufacturer Part Number ADXL343BCCZ
U302: ECS00030; ECMSOP-8; Manufacturer Part Number MCP6042-E/MS

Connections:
/Sensing/AIR_PRESSURE_1: P302.3, U302.3 (+)
AIR_PRESSURE_1_A/D: C304.2, R309.2; also elsewhere on the board
GNDA: C303.2, C304.1, C305.1, Q301.2 (S), R301.1, R307.2, U302.4 (V-); also elsewhere on the board
GNDD: C301.2, C302.2, U301.2 (GND), U301.4 (GND), U301.5 (GND), U301.12 (SDO/ALT_ADDRESS); also elsewhere on the board
unnamed: D301.2 (A), Q302.1 (B), R302.2
unnamed: P303.1, Q301.3 (D), R302.1, R306.1
unnamed: P303.2 (PM), Q302.3 (C), R305.1
unnamed: Q301.1 (G), R303.2
unnamed: Q302.2 (E), R304.1
unnamed: R305.2, R307.1, U302.5 (+)
unnamed: R306.2, R308.1, U302.6 (-)
unnamed: R308.2, R310.1, U302.7
unnamed: R309.1, U302.1, U302.2 (-)
SCL: P301.2, U301.14 (SCL/SCLK); also elsewhere on the board
SDA: P301.1, U301.13 (SDA/SDI/SDIO); also elsewhere on the board
VAA: C303.1, D301.1 (K), R304.2, U302.8 (V+); also elsewhere on the board
VDD: C301.1, C302.1, U301.1 (VDD_I/O), U301.6 (VS), U301.7 (~CS); also elsewhere on the board
WATER_DEPTH_A/D: C305.2, R310.2; also elsewhere on the board
WATER_DEPTH_ON/OFF: R301.2, R303.1; also elsewhere on the board

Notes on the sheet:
Accelerometer
I2C address is 0x53 (followed by the R/W bit) This translates to 0xA6 for a write and 0xA7 for a read.
Precision resistor may be required
Water Depth Sensor
Current = 22 mA
Vz = 1.8V
Output From Power Board
Pressure 1 = 100 PSI Pressure 2 = 30 PSI (now I2C)
Tant cap C12 must be placed close to VS
Receives signal from 100PSI pressure sensor
Not used anymore

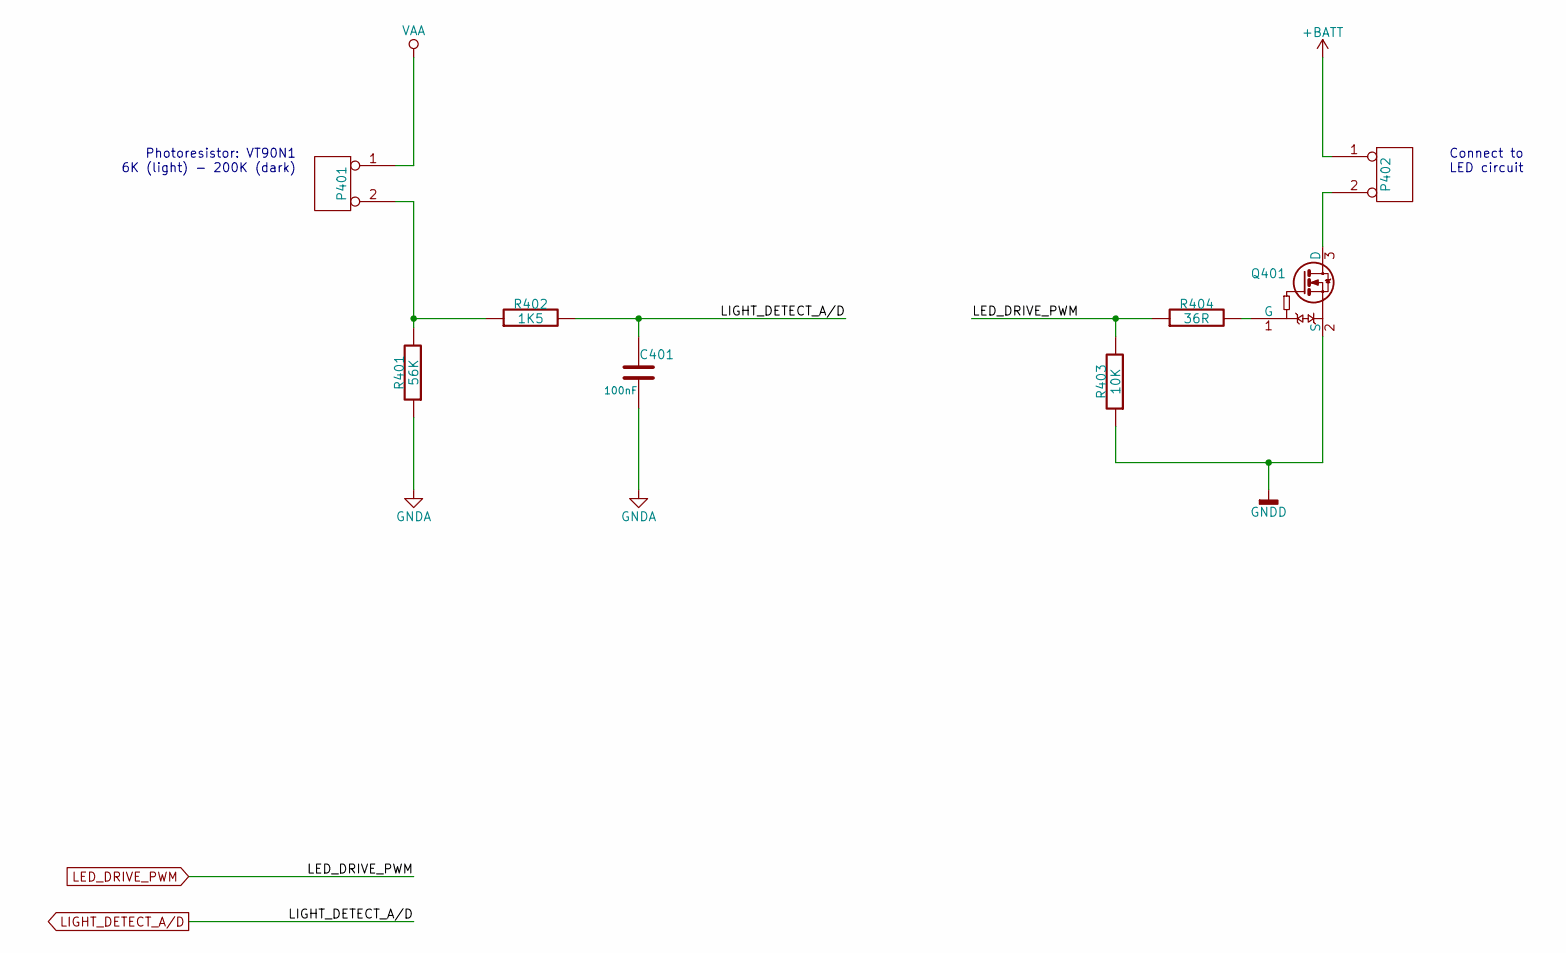
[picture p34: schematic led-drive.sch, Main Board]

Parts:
C401: ECS00075; EC0603_C; Manfacturer Part Number GRM188R71C104KA01D
P401, P402: ECS00067; ECS00067F; Manufacturer Part Number B2B-PH-SM4-TB(LF)(SN)
Q401: ECS00087; ECSOT416; Manufacturer Part Number NTA4153NT1G
R401: ECS00085; EC0603; Manufacturer Part Number CRCW060356K0FKEAHP
R402: ECS00083; EC0603; Manufacturer Part Number CR0603-FX-1501ELF
R403: ECS00045; EC0603; Manufacturer Part Number ERJ3GEYJ103V
R404: ECS00080; EC0603; Manufacturer Part Number CRCW060336R0FKEA

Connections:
+BATT: P402.1; also elsewhere on the board
GNDA: C401.2, R401.1; also elsewhere on the board
GNDD: Q401.2 (S), R403.1; also elsewhere on the board
LED_DRIVE_PWM: R403.2, R404.1; also elsewhere on the board
LIGHT_DETECT_A/D: C401.1, R402.2; also elsewhere on the board
unnamed: P401.2 (PM), R401.2, R402.1
unnamed: P402.2 (PM), Q401.3 (D)
unnamed: Q401.1 (G), R404.2
VAA: P401.1; also elsewhere on the board

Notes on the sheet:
Connect to LED circuit
Photoresistor: VT90N1 6K (light) - 200K (dark)

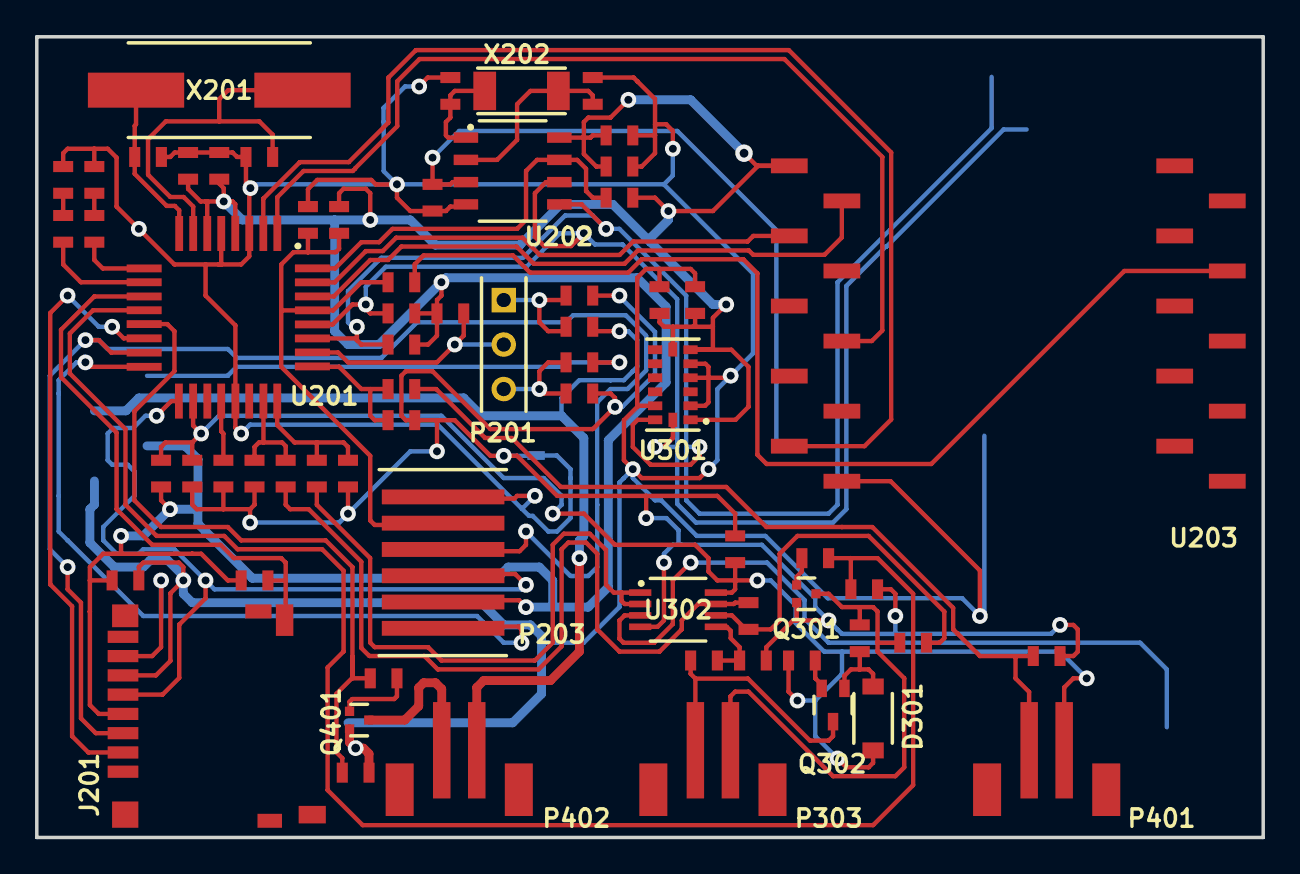
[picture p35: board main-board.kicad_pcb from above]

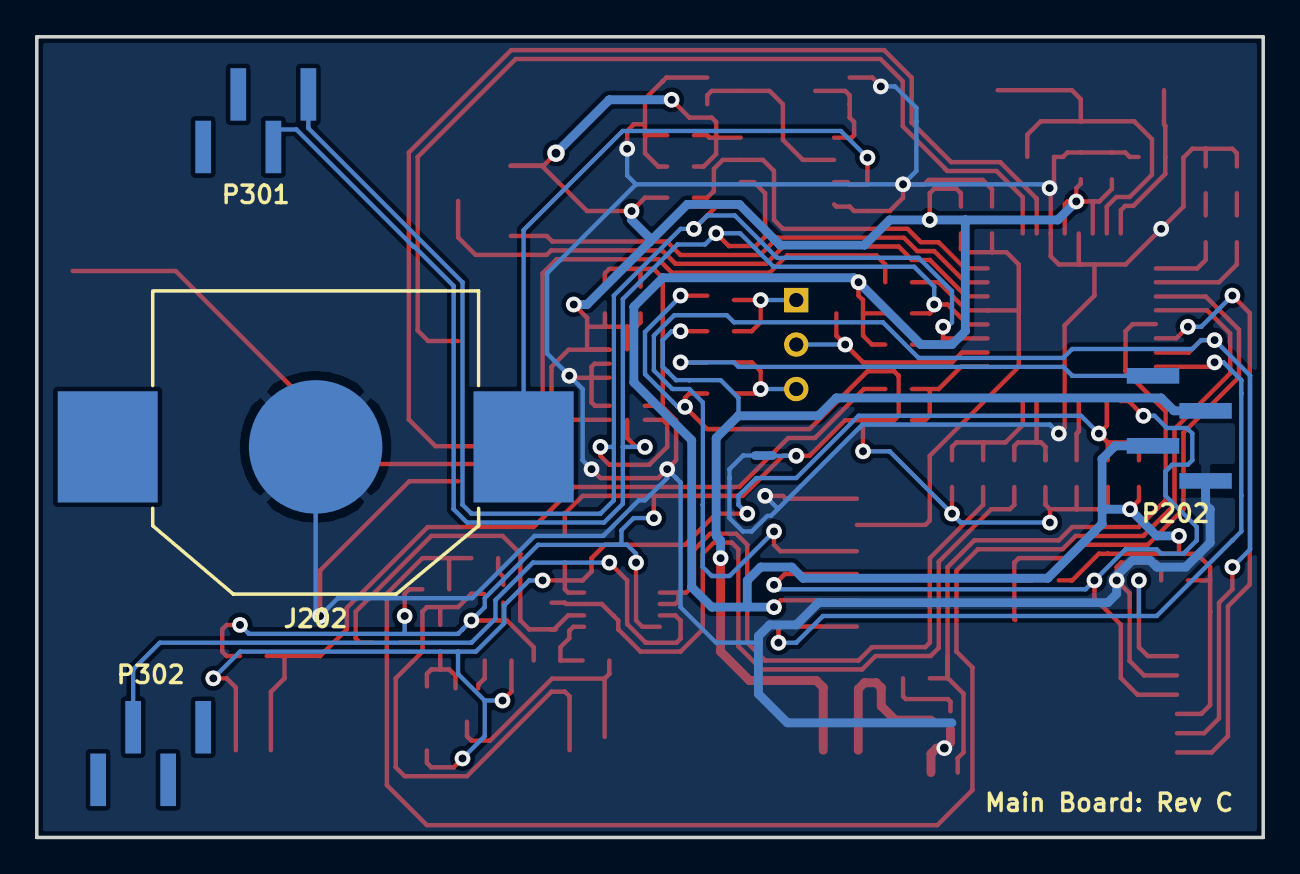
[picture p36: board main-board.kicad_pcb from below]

Board: 2 copper layers, 70.0 x 45.7 mm, 71 parts (5 on the bottom side), 51 nets.

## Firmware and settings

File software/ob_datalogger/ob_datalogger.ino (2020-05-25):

/*
Ocean Buoy Data Logger - Arduino Firmware
Rev 1.0
Author: Andrew Li
Year: 2014

*/

// DEFINES
//#define DEBUG // Code will not work with debug defined as Serial.print cause SRAM to run out, which in turn stops SD card functions to work properly
#define LED_PULSE
//#define SAFETY_LIGHT_ACTIVE
#define COMMAND_SIZE 4
#define SERIAL_BR 57600 // Communication baud rate for UART serial
#define SAMPLING_FREQ 2
#define LEN_HEADER_STRING 160

// EEPROM ADDRESS MAPPING
#define START_YEAR 0
#define START_MONTH 1
#define START_DAY 2
#define START_HOUR 3
#define START_MINUTE 4
#define START_SECOND 5

#define END_YEAR 6
#define END_MONTH 7
#define END_DAY 8
#define END_HOUR 9
#define END_MINUTE 10
#define END_SECOND 11

//#define LIGHT_THRESHOLD_LOW 12
//#define LIGHT_THRESHOLD_HIGH 13

// LIGHT THRESHOLD VALUES. These must be between 0 and 255 (8 bits)
#define LIGHT_THRESHOLD_VALUE_LOW 200
#define LIGHT_THRESHOLD_VALUE_HIGH 210

// INCLUDES
#include "Arduino.h"
#include <EEPROM.h>
#include "Wire.h"
#include <BQ32000.h>
#include <SD.h> // For handling SD card functions.
#include <ADXL345.h> // This library can also be used with ADXL343. It is address compatible.
#include <SSC.h> // for 30PSI pressure sensor
#include <avr/pgmspace.h>

// PIN ASSIGNMENTS

// Interrupt pins
const uint8_t isr_rtc = 0;
const uint8_t isr_xrf = 1;

// Analog pins
const uint8_t pin_water_depth = A0;
const uint8_t pin_air_pressure_1 = A1;
const uint8_t pin_light_detect = A2;
const uint8_t pin_vmeasure = A3;

// LED drive
const uint8_t pin_led_drive = 9;

// Current source drive for water depth measurement
const uint8_t pin_current_source_drive = 8;

// Output LEDs for development
const uint8_t pin_led_ind_1 = 5;
const uint8_t pin_led_ind_2 = 6;

// Chip select pin for SD MISO
const uint8_t pin_chip_select = 10;

// XRF Wireless Comms
const uint8_t pin_wireless_comms_shutdown = 4;
const uint8_t pin_wireless_comms_heartbeat = 3;

// GLOBALS
unsigned int water_depth = 0;
unsigned int air_pressure_1 = 0; // From 100PSI analog pressure sensor
unsigned int air_pressure_2 = 0; // From 30PSI digital I2C pressure sensor
unsigned int temperature = 0;
unsigned int light_level = 0;
unsigned int voltage_measurement = 0; // This can be either the battery voltage or the voltage of the solar panels.
int accel_x,accel_y,accel_z; // The X, Y and Z acceleration. Acceleration can have negative values, hence using int.
unsigned int time[6]; // An array for storing the time. The order for time[6] is YY MM DD HH MM SS

// OBJECTS
ADXL345 ADXL; // Variable ADXL is an instance of the ADXL345 library
SSC SSCSensor(0x28); // Variable SSCSensor is the handle to access the SSC 30PSI Pressure Sensor. 0x28 is the I2C address

// STORING DATA. Data should be stored in this order. This string is long, so store in program memory
//const prog_char header_string[] PROGMEM = {"Data Point Counter, Water Depth, Air Pressure (100PSI), Air Pressure (30PSI), Temperature, Light Level, Voltage, Acceleration X, Acceleration Y, Acceleration Z"};
const prog_char header_string[] PROGMEM = {"dpc,wd,ap100,ap30,tmp,llvl,v,ax,ay,az"};
String filename = ""; // String for holding the filename of the datafile

// FLAGS
bool flag_create_new_file = 0;
bool flag_error = 0;
bool flag_flashSafetyLight = 0;
bool flag_start = 0;

// COUNTERS
uint8_t isr_count = 0;
unsigned int write_count = 1;

// LED Drive Variables
uint8_t counter1;
uint8_t counter2;
bool led_switch;
bool led_state;

// We are using uint8_t (BYTE) because we want to be able to store these values in EEPROM
uint8_t lightThresholdLow;
uint8_t lightThresholdHigh;
const uint8_t duty_cycle = 50; // Should be a value between 0 and 100
const uint8_t nunber_of_flashes = 5;

void setup() {
	
	// Initialise the serial port
	Serial.begin(SERIAL_BR);
	
	// Initialise peripherals
	initialisePins();
	initialiseAccel();
	initialisePressureSensor30SPI();
	initialiseSD(); // This will also set the flag_create_new_file = 1
	initialiseRTC();
	initialiseSafetyLight();
	attachInterrupt(isr_rtc, rtcISR, CHANGE); // A CHANGE interrupt triggers every 500ms
}

void loop() {
	// The code is design to be interrupt driven, hence no code here
}

// This ISR is triggered every 500ms by the square wave output from RTC
void rtcISR() {
	
	#ifdef SAFETY_LIGHT_ACTIVE
	
	if (flag_flashSafetyLight) {
		activateSafetyLight();
	}
	
	#endif
	
	interrupts();
	mainRoutine();
	noInterrupts();
}

// This function executes when there is data recevied from serial port
void serialEvent() {
	
	delay(50); // Give sufficient time for data to stream to Arduino
	String query = retrieveSerial();
	Serial.print("Query is: ");
	Serial.println(query);
	interpretCommand(query);
}

// The bulk of the code will reside here. This routine must complete within 500ms
void mainRoutine() {
	
	// To signal the start of the main routine
	#ifdef LED_PULSE
	digitalWrite(pin_led_ind_2, HIGH);
	#endif
	
	switch (flag_error) {
		
		case 0:
		// Analog measurements
		water_depth = measureWaterDepth();
		air_pressure_1 = measureAirPressure100PSI();
		light_level = measureLightLevel();
		flag_flashSafetyLight = doesSafetyLightNeedToSwitchOn(light_level);
		voltage_measurement = measureVoltage();

		// IC2 DEVICES - Digital measurements
		accel_x = readAccelerationX(); // measure X acceleration
		accel_y = readAccelerationY(); // measure Y acceleration
		accel_z = readAccelerationZ(); // measure Z acceleration
		
		air_pressure_2 = measureAirPressure30PSI();
		temperature = measureTemperature();
		
		if (!flag_create_new_file) {
			flag_create_new_file = isStartOfNewHour();
		}

		saveData(); // Save data to SD
		
		write_count++;
		
		break;
		
		case 1:
		displayError();
		break; // Not needed but good practice
	}
	
	#ifdef LED_PULSE
	digitalWrite(pin_led_ind_2, LOW);
	#endif
}

void displayError() {
	digitalWrite(pin_led_ind_1, digitalRead(pin_led_ind_1) ^ 1);
}

// Initialise drive pins
void initialisePins () {
	
	// Output pins
	pinMode(pin_led_ind_1, OUTPUT);
	pinMode(pin_led_ind_2, OUTPUT);
	pinMode(pin_led_drive, OUTPUT);
	pinMode(pin_current_source_drive, OUTPUT);
	
	// Input pins. These pins are not used in this revision of the firmware
	pinMode(pin_wireless_comms_heartbeat, INPUT);
	pinMode(pin_wireless_comms_shutdown, INPUT); // For now
}

unsigned int measureVoltage() {
	return analogRead(pin_vmeasure);
}

unsigned int measureLightLevel() {
	return analogRead(pin_light_detect);
}

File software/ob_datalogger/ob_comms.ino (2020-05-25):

/*
Ocean Buoy Data Logger - Arduino Firmware
Rev 1.0
Author: Andrew Li
Year: 2014

*/

String retrieveSerial() {
	
	String cmd = "";
	char current_byte;
	while(Serial.available() > 0) {
		current_byte = Serial.read();
		cmd += String(current_byte);
	}
	return cmd;
}


void interpretCommand(String cmdString) {
	
	char cmdStringChar[cmdString.length()+1];
	cmdString.toCharArray(cmdStringChar,sizeof(cmdStringChar));

	char cmd[] = "0000";
	for (uint8_t i = 0; i < COMMAND_SIZE; i++) {
		cmd[i] = cmdStringChar[i];
	}

	if (!strcmp(cmd,"RTRV")) {
		
		setEndTime();

		char fromDate[] = "00000000";
		char toDate[] = "00000000";

		// Each parameter is 8 characters long seperated by a space
		if (sizeof(cmdStringChar) == COMMAND_SIZE+1) {
			setFromDateAsDefaultStartTime(fromDate);
			setToDateAsDefaultEndTime(toDate);
			Serial.println(fromDate);
			Serial.println(toDate);

		}
		// else if one parameter has been passed
		else if (sizeof(cmdStringChar) == 13+1) { // example: RTRV 14092320
			for (uint8_t i = 0; i < 8; i++) {
				fromDate[i] = cmdStringChar[COMMAND_SIZE+1+i];
			}
			setToDateAsDefaultEndTime(toDate);

		}
		// else if two parameters have been passed
		else if (sizeof(cmdStringChar) == 22+1) { // example: RTRV 14092320 14092420
			for (uint8_t i = 0; i < 8; i++) {
				fromDate[i] = cmdStringChar[5+i];
				toDate[i] = cmdStringChar[14+i];
			}
		}
		
		detachInterrupt(isr_rtc);
		retrieveData(fromDate, toDate);
	}
	if (!strcmp(cmd,"ECHO")) {
		if (!flag_error) {
			Serial.println("OK");
		}
	}
}

void retrieveData(char fd[], char td[]) {
	
	// Parsing
	char yearChar[] = "00";
	char monthChar[] = "00";
	char dayChar[] = "00";
	char hourChar[] = "00";
	
	// Value holders
	int fdYear;
	int fdMonth;
	int fdDay;
	int fdHour;

	int tdYear;
	int tdMonth;
	int tdDay;
	int tdHour;

	// Parsing From Date
	for (uint8_t i = 0; i < 2; i++) {
		yearChar[i] = fd[0+i];
		monthChar[i] = fd[2+i];
		dayChar[i] = fd[4+i];
		hourChar[i] = fd[6+i];
	}
	
	// Converting chars to ints
	fdYear = int(((int(yearChar[0])-48)*10) + ((int(yearChar[1])-48)*1));
	fdMonth = int(((int(monthChar[0])-48)*10) + ((int(monthChar[1])-48)*1));
	fdDay = int(((int(dayChar[0])-48)*10) + ((int(dayChar[1])-48)*1));
	fdHour = int(((int(hourChar[0])-48)*10) + ((int(hourChar[1])-48)*1));

	// Parsing To Date
	for (uint8_t i = 0; i < 2; i++) {
		yearChar[i] = td[0+i];
		monthChar[i] = td[2+i];
		dayChar[i] = td[4+i];
		hourChar[i] = td[6+i];
	}
	
	// Converting chars to ints
	tdYear = int(((int(yearChar[0])-48)*10) + ((int(yearChar[1])-48)*1));
	tdMonth = int(((int(monthChar[0])-48)*10) + ((int(monthChar[1])-48)*1));
	tdDay = int(((int(dayChar[0])-48)*10) + ((int(dayChar[1])-48)*1));
	tdHour = int(((int(hourChar[0])-48)*10) + ((int(hourChar[1])-48)*1));
	
	if ((tdYear == 0) && (tdMonth == 0) && (tdDay == 0) && (tdHour == 0)) {
		tdYear = EEPROM.read(6);
		tdMonth = EEPROM.read(7);
		tdDay = EEPROM.read(8);
		tdHour = EEPROM.read(9);
	}
	
	if ((fdYear == 0) && (fdMonth == 0) && (fdDay == 0) && (fdHour == 0)) {
		fdYear = EEPROM.read(0);
		fdMonth = EEPROM.read(1);
		fdDay = EEPROM.read(2);
		fdHour = EEPROM.read(3);
	}

	unsigned long filenameIntFrom = 0;
	unsigned long filenameIntTo = constructFilename(tdYear,tdMonth,tdDay,tdHour);
	
	String filenameString = "";
	char filenameCharFrom[] = "00000000.CSV";
	
	File dataFile;

	do {
		filenameIntFrom = constructFilename(fdYear,fdMonth,fdDay,fdHour);
		filenameString = String(filenameIntFrom) + ".CSV";
		filenameString.toCharArray(filenameCharFrom,sizeof(filenameCharFrom));
		
		dataFile = SD.open(filenameCharFrom);
		if (dataFile) {
			
			Serial.print("file: ");
			Serial.println(filenameCharFrom);

			// read from the file until there's nothing else in it:
			while (dataFile.available()) {
				Serial.write(dataFile.read());
				delay(1); // To give sufficient time for the serial to transmit
			}
			// close the file:
			dataFile.close();
		}
		else {
			// if the file didn't open, print an error:
			Serial.print("Cannot open: ");
			Serial.println(filenameCharFrom);
		}
		
		updateTime(&fdYear, &fdMonth, &fdDay, &fdHour);
		
	} while (filenameIntFrom < filenameIntTo);
	
	Serial.println("Transmission complete!");
	flag_create_new_file = 1; // We want to restart logging to a new file.
	attachInterrupt(isr_rtc, rtcISR, CHANGE); // A CHANGE interrupt triggers every 500ms
}


unsigned long constructFilename(int fdYear, int fdMonth, int fdDay, int fdHour) {
	unsigned long result;
	result = (unsigned long)fdYear*1000000 + (unsigned long)fdMonth*10000 + (unsigned long)fdDay*100 + (unsigned long)fdHour*1;
	return result;
}

void updateTime(int* fdYear, int* fdMonth, int* fdDay, int* fdHour) {
	(*fdHour)++;
	if (*fdHour > 23) {
		(*fdHour) = 0;
		(*fdDay)++;
		if (*fdDay > daysInMonth(*fdMonth)){
			(*fdDay) = 1;
			(*fdMonth)++;
			if (*fdMonth > 12) {
				(*fdMonth) = 1;
				(*fdYear)++;
				if ((*fdYear) > 99) {
					(*fdYear) = 0;
				}
			}
		}
	}
}

int daysInMonth(int month) {
	if ((month == 1) || (month == 3) || (month == 5) || (month == 7) || (month == 8) || (month == 10) || (month == 12)) {
		return 31;
	}
	else if  ((month == 4) || (month == 6) || (month == 9) || (month == 11)) {
		return 30;
	}
	else {
		return 28; // February. Leap years are not considered in this version of the firmware
	}
}

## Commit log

2020-05-15 First commit of files.
    [Power Board-B_Cu.gbl, Power Board-B_Mask.gbs, Power Board-B_Paste.gbp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]
2020-05-22 Added output files, gerbers, dril files, raster images, and updates to PCB design files.
    [bom.xlsx, led-drive.sch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]
2020-05-23 Commiting assembly data for Main Board.
    [bom-main-board.xlsx, main-board.kicad_pcb]
2020-05-24 Updating excel file for BOM.
    [bom-main-board.xlsx]
2020-05-24 Commit fabrication files.
    [main-board.kicad_pcb]
2020-05-25 Commiting power board output files.
    [Power Board-B_Cu.gbl, Power Board-B_Mask.gbs, Power Board-B_Paste.gbp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]
2020-05-25 Adding new schematic files.
2020-05-25 Adding pick and place files for power board.
2020-05-25 Adding top and bottom solder mask gerbers.
    [power-board-B_Mask.gbs, power-board-F_Mask.gts]
